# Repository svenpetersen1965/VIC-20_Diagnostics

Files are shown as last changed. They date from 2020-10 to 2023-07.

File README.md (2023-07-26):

# VIC-20_Diagnostics
This is a diagnostic  harness and the description of the diagnostic cartridge for the Commodore VIC-20, based on the original Commodore diagnostic harness and software.

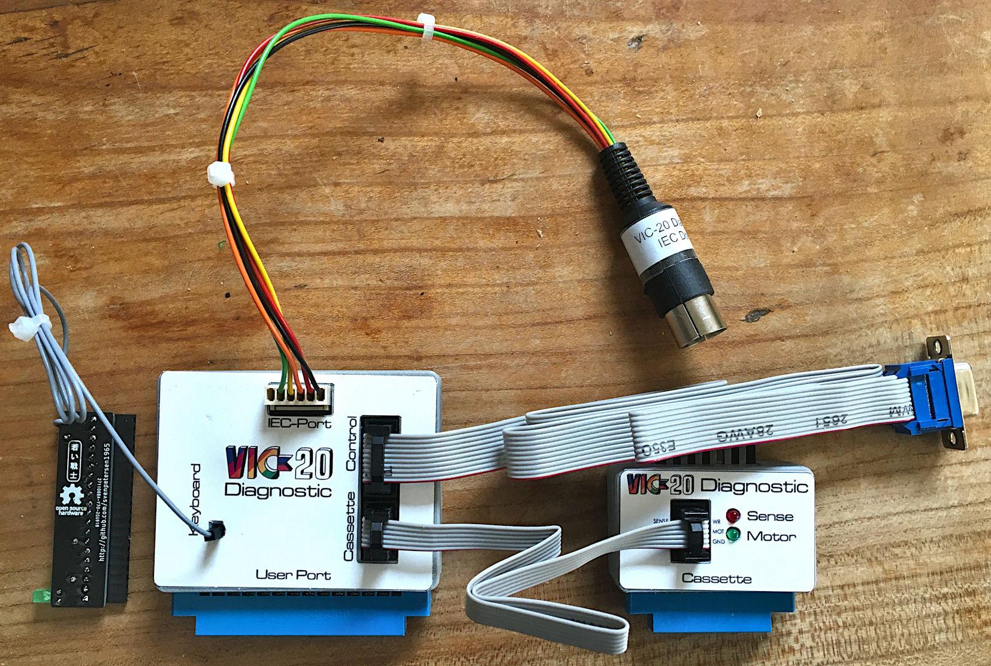
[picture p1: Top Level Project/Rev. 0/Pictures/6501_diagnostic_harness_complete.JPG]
Diagnostic Harness


The Diagnostic Cartridge is based on the design for the <a href="https://github.com/svenpetersen1965/Commodore-VIC-20-Super-Expander-II">VIC-20 Super Expander II</a> design.

Alternatively, the <a href="https://github.com/svenpetersen1965/VIC-20-Hyper-Expander">Hyper Expander</a> Cartridge can be used as a Diagnostic cartridge, too. All RAM (except the BLK5 8K block) can be installed for the Diagnostic.  

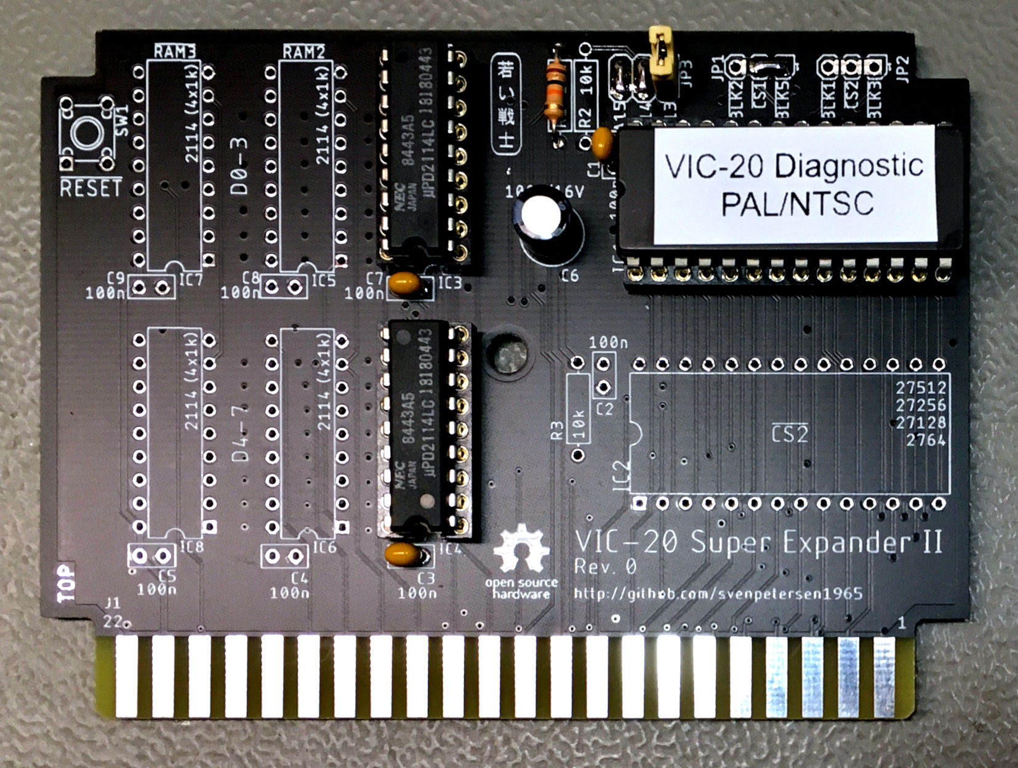
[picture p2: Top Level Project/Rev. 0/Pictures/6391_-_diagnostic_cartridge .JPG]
Diagnostic Cartridge


The general description of the VIC-20 Diagnostics can be found in the "Top-Level Project" folder.

The Rev. 1 of the User Port PCB just has a reduced part count.and a new logo.

Please find the (C64) cassette port adapter <a href="https://github.com/svenpetersen1965/C64-Diagnostic-Rev.-586220-Harness/tree/master/Diag586220_Harness/Diag586220_Cassette_Port">here</a>.

Please also refer to <a href="http://tech.guitarsite.de/vic-20_diagnostics.html">my website</a>

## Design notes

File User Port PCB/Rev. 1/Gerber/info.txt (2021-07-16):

      
       Board: VIC20_Diag_UP
       Rev.:  1
  
       Files:
       ======
  
       All Gerber files are generated in extended gerber format (RS274X)
       *.TOP        : Film top copper
       *.BOT        :  -"- bottom copper
       *.STC        :  -"- top soldermask 
       *.STS        :  -"- bottom soldermask
       *.PLC        :  -"- silk screen top
       *.DK         : Drills plated Through (Excellon)
       *.NDK        : Drills not plated Through (Excellon)
       *.OUT        : Board outline

       Board Size:
       ===========
       Length     :   55.0 mm
       Width      :   53.0 mm
       Thickness  :   1.6 mm
       Material   :   FR 4
       Copper     :   35 um
       Surface    :   HASL
       
       Remarks:
       ========
       Width >= 8mil
       Distance >= 6mil
       Drill >= 0.35mm

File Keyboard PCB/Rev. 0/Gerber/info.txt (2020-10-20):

      
       Board: VIC20_Diag_Keyboard
       Rev.:  0
  
       Files:
       ======
  
       All Gerber files are generated in extended gerber format (RS274X)
       *.TOP        : Film top copper
       *.BOT        :  -"- bottom copper
       *.STC        :  -"- top soldermask 
       *.STS        :  -"- bottom soldermask
       *.PLC        :  -"- silk screen top
       *.PLS        :  -"- silk screen bottom
       *.DK         : Drills plated Through (Excellon)
       *.NDK        : Drills not plated Through (Excellon)
       *.OUT        : Board outline

       Board Size:
       ===========
       Length     :   53.0 mm
       Width      :   14.0 mm
       Thickness  :   1.6 mm
       Material   :   FR 4
       Copper     :   35 um
       Surface    :   HASL
       
       Remarks:
       ========
       Width >= 8mil
       Distance >= 6mil
       Drill >= 0.35mm

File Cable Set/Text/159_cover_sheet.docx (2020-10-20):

Project Documentation

Commodore VIC-20: Diagnostic Cable Set

Project number: 159

Revision: 0

Date: 18.10.2020

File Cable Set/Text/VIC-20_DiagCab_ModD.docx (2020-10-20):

Commodore VIC-20: Diagnostics Cable Set – Rev. 0

Module Description

The Diagnostic cable set is one components of the VIC-20 Diagnostics Harness. It consists of four cables:

- The IEC Port Cable (Doc.-No. 159-3-01-**)
- The Control Port Cable (Doc.-No. 159-3-02-**)
- The Cassette Port Cable (Doc.-No. 159-3-03-**)
- The Keyboard RESTORE cable (Doc.-No. 159-3-04-**)

The Keyboard RESTORE cable is attached to the Keyboard PCB (Project-No. 156), a know serves as a strain relief.

The Control Port cable and the Cassette Port cable are both identical to the cables of the C64 diagnostic harness.

VIC-20_DiagCab_ModD.docx 18.10.2020 16:29 Drafted by Sven Petersen Page 2 of 2 Doc.-No.: 159-6-01-00

VIC-20_DiagCab_ModD.docx 18.10.2020 16:29 Drafted by Sven Petersen Page 1 of 1 Doc.-No.: 000-6-00-00

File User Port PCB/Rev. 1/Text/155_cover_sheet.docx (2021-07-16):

Project Documentation

Commodore VIC-20 Diagnostic User Port PCB

Project number: 155

Revision: 1

Date: 14.07.2021

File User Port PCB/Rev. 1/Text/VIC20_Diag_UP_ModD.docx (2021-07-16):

Commodore VIC-20 Diagnostic User Port PCB Rev. 1

Module Description

The VIC-20 Diagnostics User Port PCB provides most of the required feedbacks for the Commodore Diagnostic Software. Those are the feedbacks for the User Port, the IEC (serial) bus and the Cassette Port. Only the keyboard feedbacks are realized on the Diagnostic Keyboard PCB.

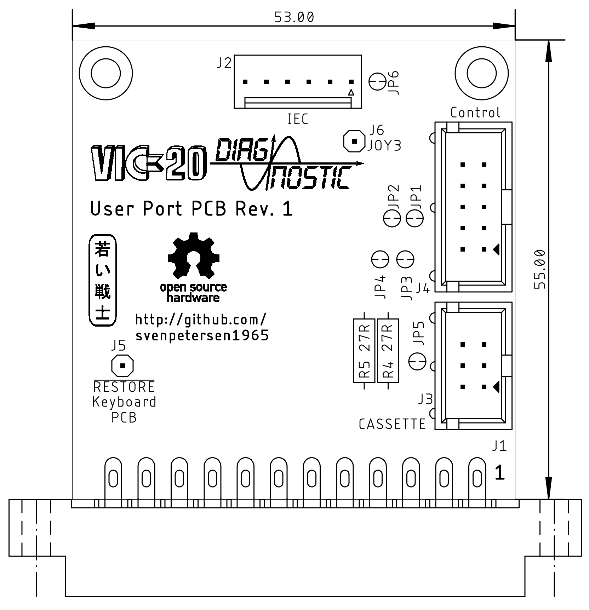
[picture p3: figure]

Figure 1: Dimensions of the User Port PCB

# Connectors

## User Port

J1- Edge Connector (2x12, 3.96mm pitch)

Pin | Signal | Pin | Signal
1 | GND | A | GND
2 | +5V | B | CB1
3 | /RESET | C | PB0
4 | JOY0 | D | PB1
5 | JOY1 | E | PB2
6 | JOY2 | F | PB3
7 | LIGHTPEN | H | PB4
8 | CASSSW | J | PB5
9 | ATN | K | PB6
10 | 9VAC(1) | L | PB7
11 | 9VAC(2) | M | CB2
12 | GND | N | GND

## IEC-Bus

J2 – KF2510, 6pin (compatible to Molex KK 254 series, 6p. - P/N 22272061)

Pin | Signal | DIN 6
1 | SQR IN | 1
2 | GND | 2
3 | ATN | 3
4 | CLK | 4
5 | DATA | 5
6 | n.c | -

## Cassette Port

J3 – 2x3 pin header for a ribbon cable connected to the cassette port PCB (project number 114, from the C64 Diagnostic Harness).

Pin | Signal | Pin | Signal
1 | GND | 2 | n.c.
3 | MOTOR | 4 | READ
5 | WRITE | 6 | SENSE

## Control Port

J4 – 2x5 pin header for a ribbon cable which connects via a D-SUB 9 (female) to the control port.

Pin | D-SUB | Signal | Pin | D-SUB | Signal
1 | 1 | JOY0 (up) | 2 | 6 | LIGHTPEN
3 | 2 | JOY1 (down) | 4 | 7 | +5VCTR1
5 | 3 | JOY2 (left) | 6 | 8 | n.c. (GND)
7 | 4 | JOY3 (right) | 8 | 9 | POTX
9 | 5 | POTY | 10 | - | n.c.

# Feedbacks

## User Port (J1)

Pin | Signal | | Signal | Pin
B | CB1 | « | IEC-Data | J2/Pin 5
C | PB0 | « | PB1 | D
E | PB2 | « | PB3 | F
H | PB4 | « | PB5 | J
K | PB6 | « | PB7 | L
M | CB2 | « | IEC-Clk | J2/Pin 4
9 | ATN | « | KB | See J5

## IEC-Bus (J2)

Pin | Signal | | Signal | Pin
1 | SQR_IN | « | ATN | 3
4 | IEC-Clk | « | CB2 (User Port) | J1/Pin M
5 | IEC-Data | « | CB1 (User Port) | J1/Pin B

## Cassette Port (J3)

Pin | Signal | | Signal | Pin
1 | GND | | n/c | 2
3 | MOTOR | Volt.div. | SENSE | 6
4 | READ | « | WRITE | 5

## Control Port (J4)

DSub | J4 Pin | Signal | | Signal | J4 Pin | DSub
1 | 1 | JOY0 | « | JOY1 | 3 | 2
6 | 2 | LIGHTPEN/FIRE | « | JOY2 | 5 | 3
9 | 8 | POTX | « | +5V (Control Port) | 4 | 7
5 | 9 | POTY | « | +5V (Control Port) | 4 | 7

The JOY3 signal is not tested by the original harness. It is connected to the solder pad J6 for experimental purposes.

## Note

The former 0Ω resistor have been replaced with closed (by default) solder bridges. This is to reduce the part count. They don’t serve any purpose, so leave them as is.

# 3D-printed Case

A 3D-printed case for the User Port PCB is available from this repository. The recommended screws are C2.9 x 9.5mm.

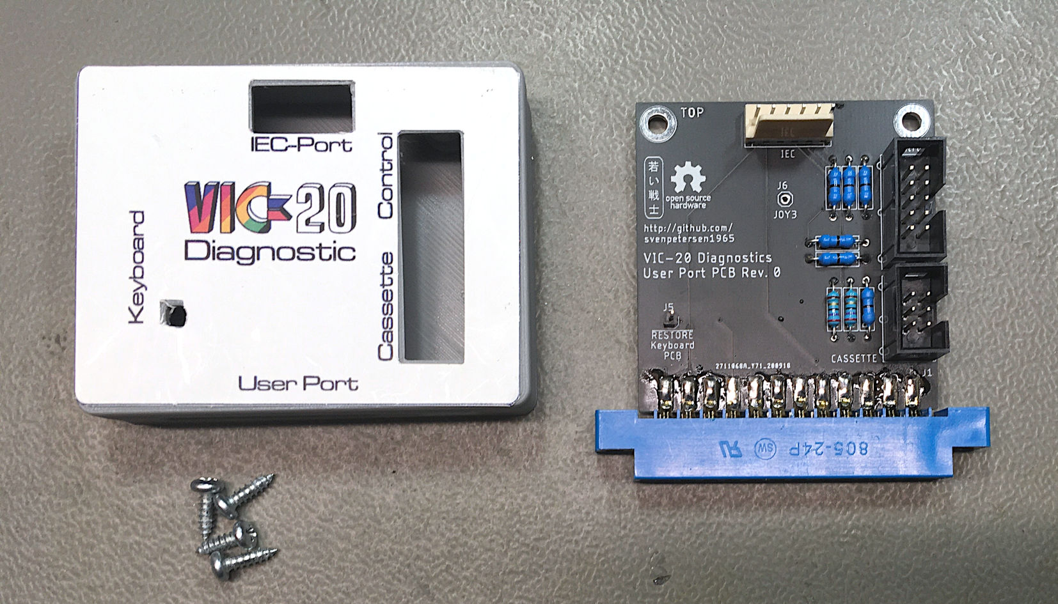
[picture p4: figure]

Figure 2: User Port PCB with 3D-printed case

# Revision History

## Rev. 0

- Fully working prototype

## Rev. 1

- 0Ω resistors replaced with closed solder bridges to reduce part count
- Cool new logo
- Not yet tested, but low risk modification. Ready for production.

VIC20_Diag_UP_ModD.docx 16.07.2021 13:00 Drafted by Sven Petersen Page 2 of 2 Doc.-No.: 155-6-01-01

VIC20_Diag_UP_ModD.docx 16.07.2021 13:00 Drafted by Sven Petersen Page 1 of 1 Doc.-No.: 000-6-00-00

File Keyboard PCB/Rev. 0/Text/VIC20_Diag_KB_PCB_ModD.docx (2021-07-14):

Commodore VIC-20 Diagnostic Keyboard PCB Rev. 0

Module Description

The Keyboard PBC provides the feedbacks for the keyboard connector, which are required for the Commodore VIC-20 Diagnostic software. The LED works as an alternative Power LED.

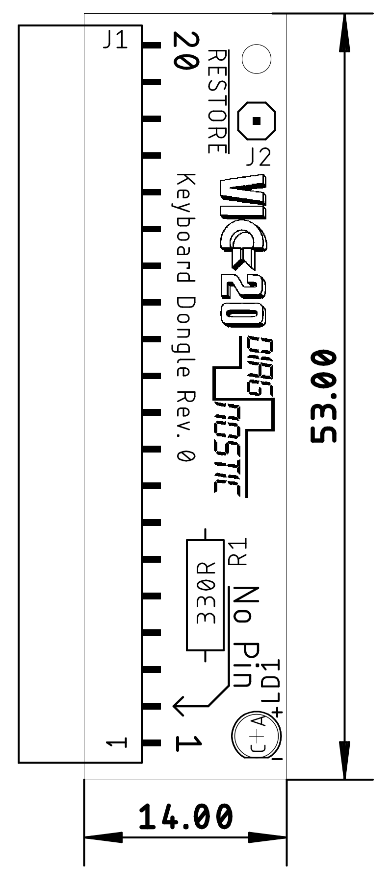
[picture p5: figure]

Figure 1: Dimensions of the Keyboard PCB

# Connectors

## Keyboard Connector (J1)

Pin | Signal
1 | GND
2 | No Pin
3
4 | +5V
5 | COL7
6 | COL6
7 | COL5
8 | COL4
9 | COL3
10 | COL2
11 | COL1
12 | COL0
13 | ROW7
14 | ROW6
15 | ROW5
16 | ROW4
17 | ROW3
18 | ROW2
19 | ROW1
20 | ROW0

## Cable (J2)

This is a solder pad for the RESTORE Cable (Doc.-No. 159-3-04-**) from the cable set. The cable is soldered to the pad and a knot serves as a strain relief.

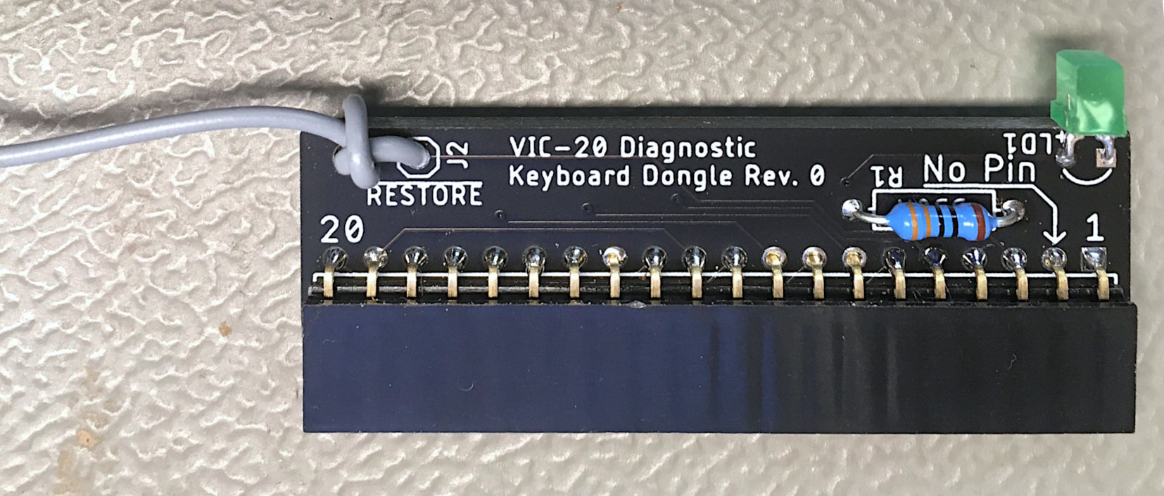
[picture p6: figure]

Figure 2: Keyboard PCB with the RESTORE cable soldered to J2 and tied to the PCB

This cable is connected to a single pin of the User Port PCB.

# Interconnects

Signal | | Signal
| → | User Port Pin 9 (ATN)
COL7 | « | ROW7
COL6 | « | ROW6
COL5 | « | ROW5
COL4 | « | ROW4
COL3 | « | ROW3
COL2 | « | ROW2
COL1 | « | ROW1
COL0 | « | ROW0

VIC20_Diag_KB_PCB_ModD.docx 14.07.2021 17:06 Drafted by Sven Petersen Page 2 of 2 Doc.-No.: 156-6-01-00

VIC20_Diag_KB_PCB_ModD.docx 14.07.2021 17:06 Drafted by Sven Petersen Page 1 of 1 Doc.-No.: 000-6-00-00

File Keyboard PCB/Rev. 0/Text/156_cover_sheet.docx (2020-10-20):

Project Documentation

Commodore VIC-20 Diagnostic Keyboard PCB

Project number: 156

Revision: 0

Date: 15.09.2020

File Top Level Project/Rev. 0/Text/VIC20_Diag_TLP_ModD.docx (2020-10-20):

Commodore VIC-20 Diagnostics (Top-Level Project) Rev. 0

Module Description

# Abstract

This is the top-level project of the VIC-20 diagnostic harness and cartridge. The whole diagnostics set consists of:

- A Diagnostic Cartridge
- A User Port PCB
- A Keyboard PCB
- A Cassette Port PCB
- A Cable Set


Figure 1: The complete Diagnostic Harness

# Diagnostics Cartridge

The diagnostic cartridge is based on the Super Expander II. It contains the diagnostic software in an EPROM and 1kByte of RAM.


Figure 2: Diagnostics Cartridge

There are two versions of the (original Commodore) test software, which were downloaded from www.zimmers.net (http://www.zimmers.net/anonftp/pub/cbm/firmware/misc/vc-20diag/index.html). One version is for the PAL VIC-20. It displays “VC-20” (like the name of the computer in Germany). The other version is for NTSC VIC-20 (it displays “VIC-20”).

Both software versions work in the IC1 socket, the chip select hardwired to (the base address is $A000). Thus, the solder bridge at JP1 as seen in Figure 2.

Since there are only two versions of the diagnostic software, two jumpers (A15 and A14) on JP3 can be hardwired (which is valid for a 27C512 EPROM). A 10k for R1 and a single jumper is required to select one of the two software versions.

EPROM | Solder bridges closed | Resistors placed
27C512 | A14, A15 | R1
27C256 | A15 | R1, R2
27C128 | - | R1, R2, R3

The EPROM IC1requires a 100n capacitor in position C1.

The RAM is only 1kByte. That are two 2114 (1kx4) SRAM at position IC3 and IC4 (with 100n at C7 and C3).

The Super Expander II cartridge can be found at github: https://github.com/svenpetersen1965/Commodore-VIC-20-Super-Expander-II

# The User Port PCB

The User Port PCB is especially developed for this project. The complete documentation, Gerber data and design files are available on github:

https://github.com/svenpetersen1965/VIC-20_Diagnostics

A 3D printable case is provided in the same repository.

# The Keyboard PCB

The Keyboard PCB is especially developed for this project. The complete documentation, Gerber data and design files are available on github:

https://github.com/svenpetersen1965/VIC-20_Diagnostics

# The Cassette Port PCB

The Cassette Port PCB is identical to the Cassette Port PCB of the C64 Diagnostic harness. It is available from github:

https://github.com/svenpetersen1965/C64-Diagnostic-Rev.-586220-Harness

A 3D printable case can be found in the same repository.

All required feedbacks are realized on the User Port PCB, which connects to the Cassette Port PCB via a ribbon cable. The cassette port PCB is free of any typical feedbacks. Two signals are indicated with LEDs.

# The Cable Set

The cable set consists of four cables:

- The IEC Port Cable
- The Control Port Cable
- The Cassette Port Cable
- The Keyboard RESTORE cable

The Control Port cable and the Cassette Port cable are identical to the C64 Diagnostic Harness cables.

The IEC-Port cable connects the IEC port to the User Port PCB, which provides the required feed backs.

The RESTORE cable connects the Keyboard PCB to the User Port PCB. This is a simple DuPont wire, which is soldered to the Keyboard PCB on one side.

The documentation for the Cable Set can be found on github:

https://github.com/svenpetersen1965/VIC-20_Diagnostics

VIC20_Diag_TLP_ModD.docx 20.10.2020 14:21 Drafted by Sven Petersen Page 2 of 2 Doc.-No.: 161-6-01-00

VIC20_Diag_TLP_ModD.docx 20.10.2020 14:21 Drafted by Sven Petersen Page 1 of 1 Doc.-No.: 000-6-00-00

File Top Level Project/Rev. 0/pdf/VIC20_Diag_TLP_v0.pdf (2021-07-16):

# Project Documentation

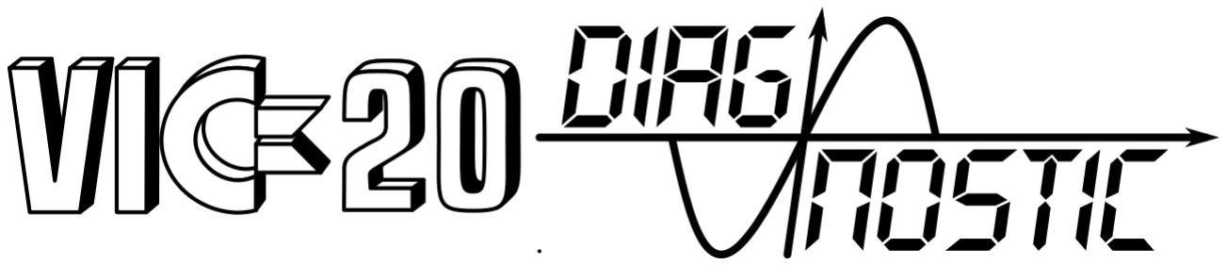
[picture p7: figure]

## Commodore VIC-20 Diagnostics (Top-Level Project)

## Project number: 161

## Revision: 0

## Date: 20.10.2020

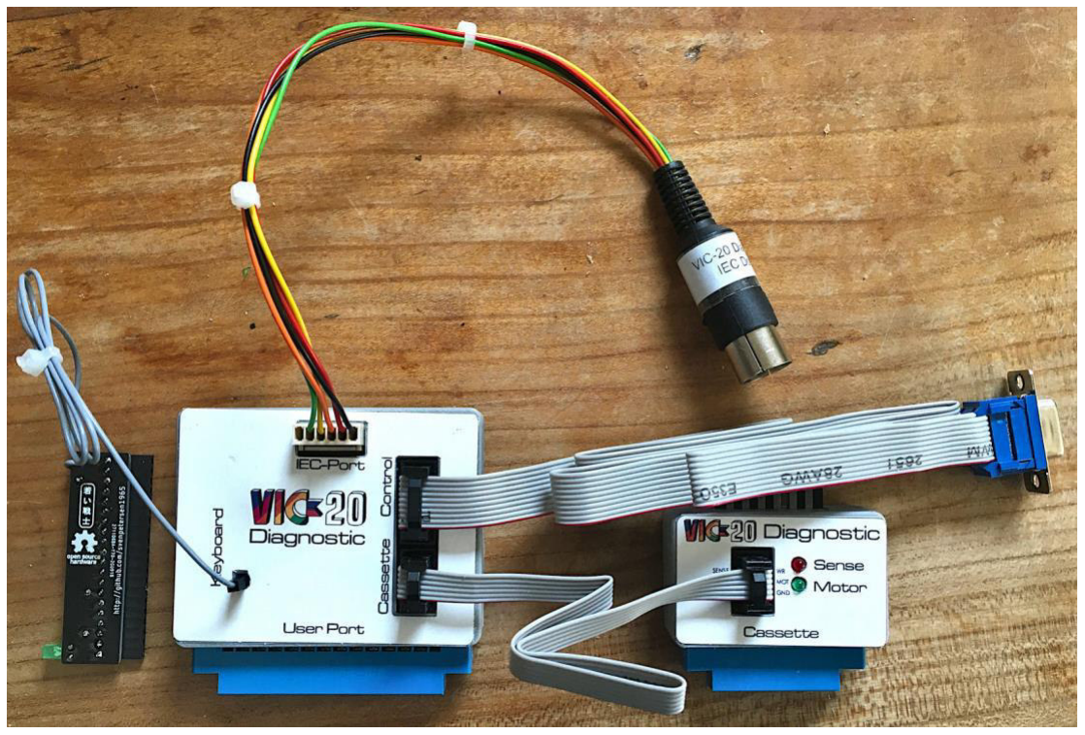
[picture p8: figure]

VIC20_Diag_TLP_ModD.docx | | 20.10.2020 14:21
Drafted by Sven Petersen | Page 1 of 3 | Doc.-No.: 161-6-01-00

### Commodore VIC-20 Diagnostics (Top-Level Project) Rev. 0

### Module Description

## Abstract

This is the top-level project of the VIC-20 diagnostic harness and cartridge. The whole diagnostics set consists of:

- A Diagnostic Cartridge
- A User Port PCB
- A Keyboard PCB
- A Cassette Port PCB
- A Cable Set

Figure 1: The complete Diagnostic Harness

## Diagnostics Cartridge

The diagnostic cartridge is based on the Super Expander II. It contains the diagnostic software in an EPROM and 1kByte of RAM.

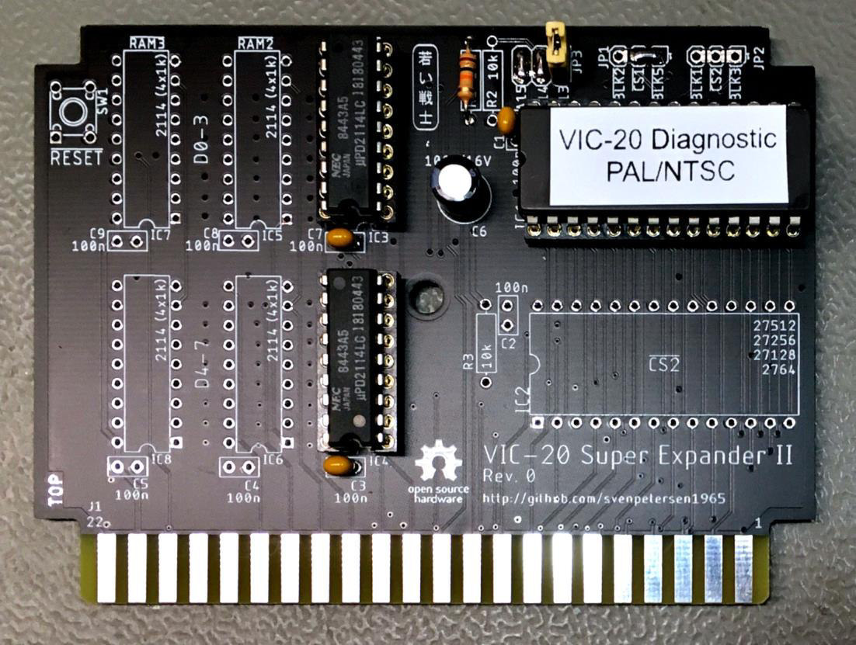
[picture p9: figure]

Drafted by Sven Petersen | Page 2 of 3 | Doc.-No.: 161-6-01-00

Figure 2: Diagnostics Cartridge

There are two versions of the (original Commodore) test software, which were downloaded from www.zimmers.net. (http://www.zimmers.net/anonftp/pub/cbm/firmware/misc/vc-20diag/index.html) One version is for the PAL VIC-20. It displays “VC-20” (like the name of the computer in Germany). The other version is for NTSC VIC-20 (it displays “VIC-20”).

Both software versions work in the IC1 socket, the chip select CS1 hardwired to BLK5 (the base address is $A000). Thus, the solder bridge at JP1 as seen in Figure 2.

Since there are only two versions of the diagnostic software, two jumpers (A15 and A14) on JP3 can be hardwired (which is valid for a 27C512 EPROM). A 10k for R1 and a single jumper is required to select one of the two software versions.

EPROM | Solder bridges closed | Resistors placed
27C512 | A14, A15 | R1
27C256 | A15 | R1, R2
27C128 | - | R1, R2, R3

The EPROM IC1requires a 100n capacitor in position C1.

The RAM is only 1kByte. That are two 2114 (1kx4) SRAM at position IC3 and IC4 (with 100n at C7 and C3).

The Super Expander II cartridge can be found at github: https://github.com/svenpetersen1965/Commodore-VIC-20-Super-Expander-II

## The User Port PCB

The User Port PCB is especially developed for this project. The complete documentation, Gerber data and design files are available on github:

Drafted by Sven Petersen | Page 3 of 3 | Doc.-No.: 161-6-01-00

https://github.com/svenpetersen1965/VIC-20_Diagnostics

A 3D printable case is provided in the same repository.

## The Keyboard PCB

The Keyboard PCB is especially developed for this project. The complete documentation, Gerber data and design files are available on github:

https://github.com/svenpetersen1965/VIC-20_Diagnostics

## The Cassette Port PCB

The Cassette Port PCB is identical to the Cassette Port PCB of the C64 Diagnostic harness. It is available from github:

https://github.com/svenpetersen1965/C64-Diagnostic-Rev.-586220-Harness

A 3D printable case can be found in the same repository.

All required feedbacks are realized on the User Port PCB, which connects to the Cassette Port PCB via a ribbon cable. The cassette port PCB is free of any typical feedbacks. Two signals are indicated with LEDs.

## The Cable Set

The cable set consists of four cables:

- The IEC Port Cable
- The Control Port Cable
- The Cassette Port Cable
- The Keyboard RESTORE cable

The Control Port cable and the Cassette Port cable are identical to the C64 Diagnostic Harness cables.

The IEC-Port cable connects the IEC port to the User Port PCB, which provides the required feed backs.

The RESTORE cable connects the Keyboard PCB to the User Port PCB. This is a simple DuPont wire, which is soldered to the Keyboard PCB on one side.

The documentation for the Cable Set can be found on github:

https://github.com/svenpetersen1965/VIC-20_Diagnostics

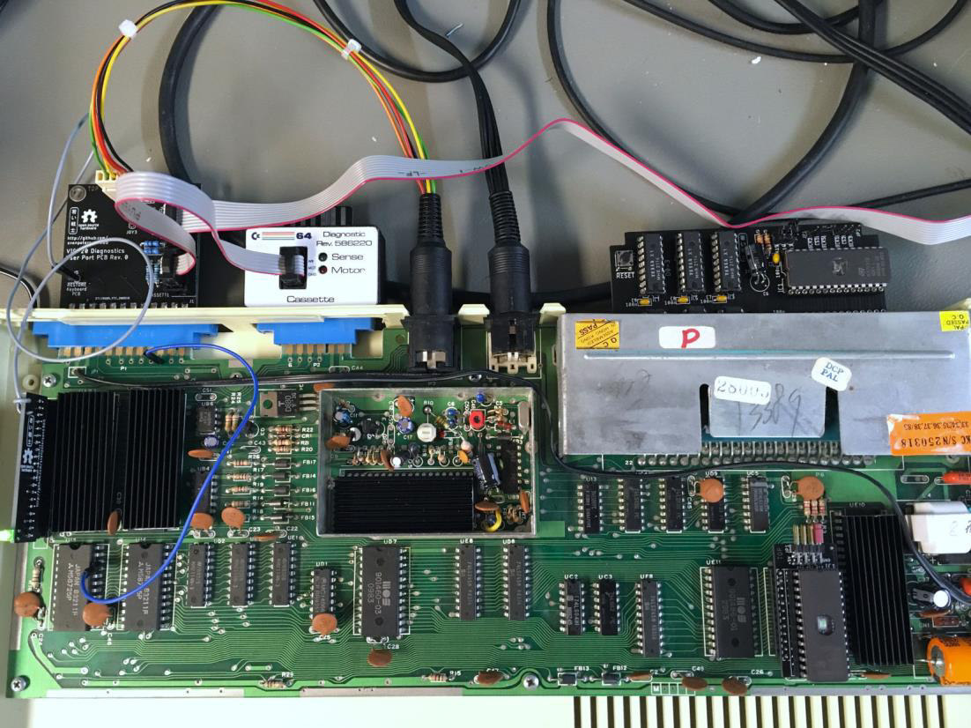
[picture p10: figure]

VIC20_Diag_TLP_Testing.docx | | 20.10.2020 16:35
Drafted by Sven Petersen | Page 1 of 3 | Doc.-No.: 161-6-02-00

### Commodore VIC-20 Diagnostics Rev. 0

### Testing

## Test Setup

The complete Diagnostics Harness (Rev. 0) and Diagnostics Cartridge (Super Expander II Rev. 0 with the Commodore Diagnostic Firmware) was tested on a VIC-20 ASSY 250403 Rev. D.

Figure 1: Test Setup

## Test Execution

The test was first carried out with a Super Expander II with 3kByte of RAM. The Test was running without any problems. Later, the not required upper 2k of RAM were removed from the board, the execution was without any problem, either.

The (Commodore) Test software stops at the first problem and the screen starts flashing. In case no problem is diagnosed, the software is looping infinitely.

There are two versions of the test software. One is for the NTSC VIC-20, the other for the PAL VIC-20. Both were working without problems on a PAL VIC-20. The position of the active was different, though.

The Feedbacks were tested by removing the feedback cables, one by one. The missing feedbacks were detected for the IEC-Bus, the Cassette Port and the Control Port. Removing the Keyboard PCB does not report and “open” like in the C64 Diagnostics Rev. 586220. It did not look like the feedbacks were diagnosed, so, one feedback (not all) was opened. The problem was properly detected.

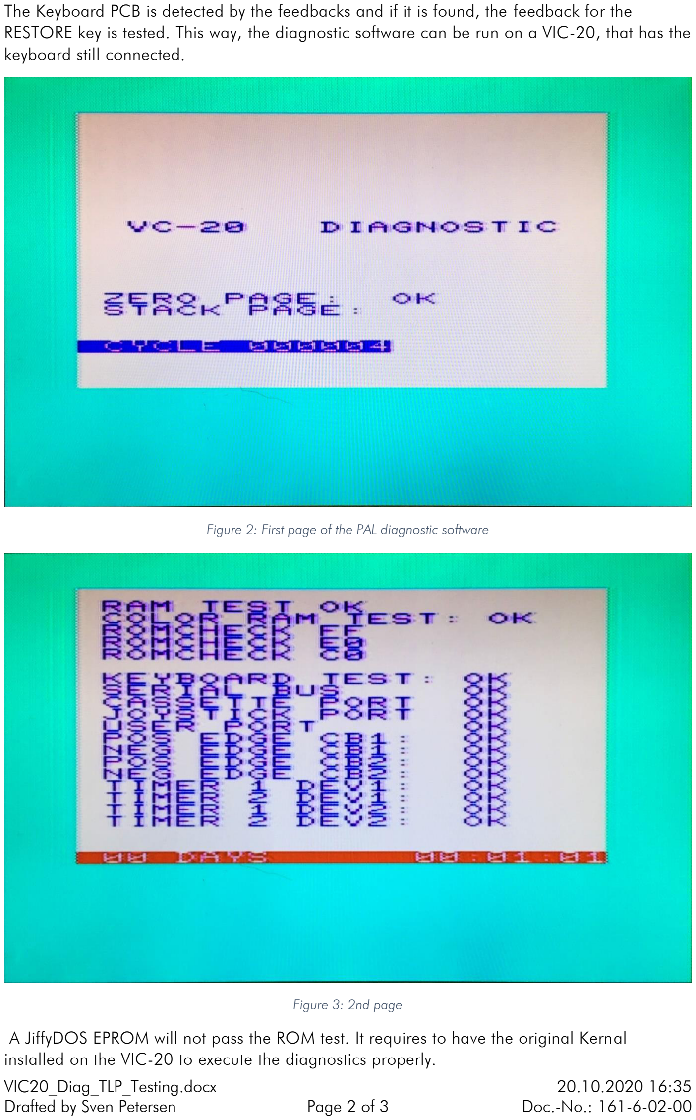
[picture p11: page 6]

Drafted by Sven Petersen | Page 2 of 3 | Doc.-No.: 161-6-02-00

The Keyboard PCB is detected by the feedbacks and if it is found, the feedback for the RESTORE key is tested. This way, the diagnostic software can be run on a VIC-20, that has the keyboard still connected.

Figure 2: First page of the PAL diagnostic software

Figure 3: 2nd page

A JiffyDOS EPROM will not pass the ROM test. It requires to have the original Kernal installed on the VIC-20 to execute the diagnostics properly.

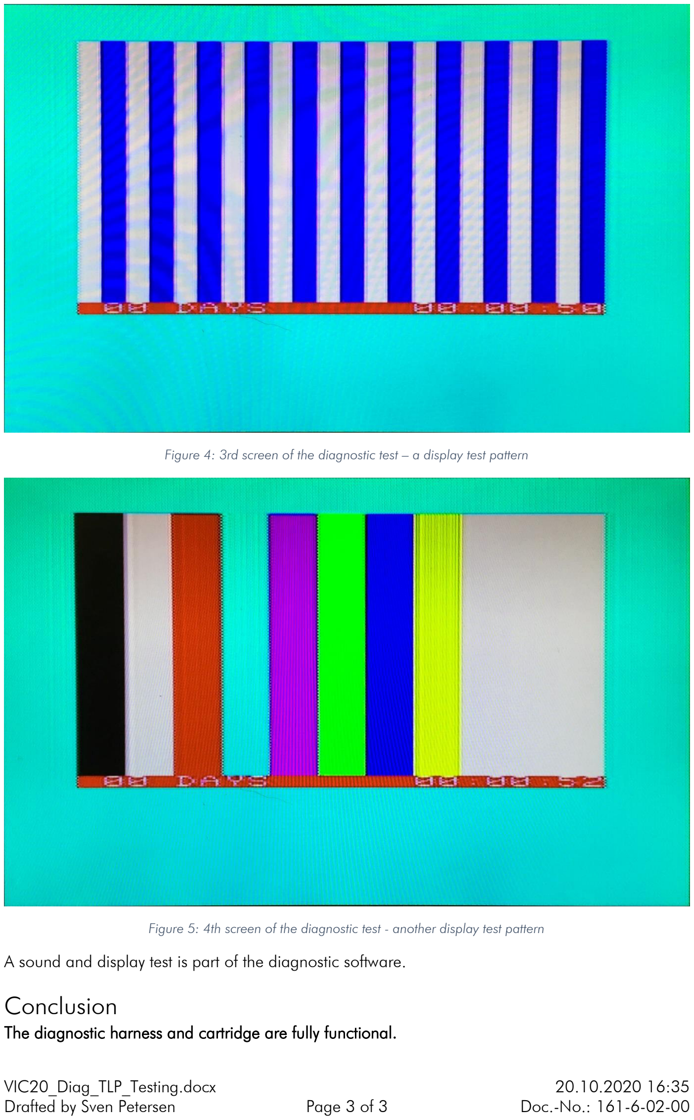
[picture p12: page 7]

Drafted by Sven Petersen | Page 3 of 3 | Doc.-No.: 161-6-02-00

Figure 4: 3rd screen of the diagnostic test – a display test pattern

Figure 5: 4th screen of the diagnostic test - another display test pattern

A sound and display test is part of the diagnostic software.

## Conclusion

The diagnostic harness and cartridge are fully functional.

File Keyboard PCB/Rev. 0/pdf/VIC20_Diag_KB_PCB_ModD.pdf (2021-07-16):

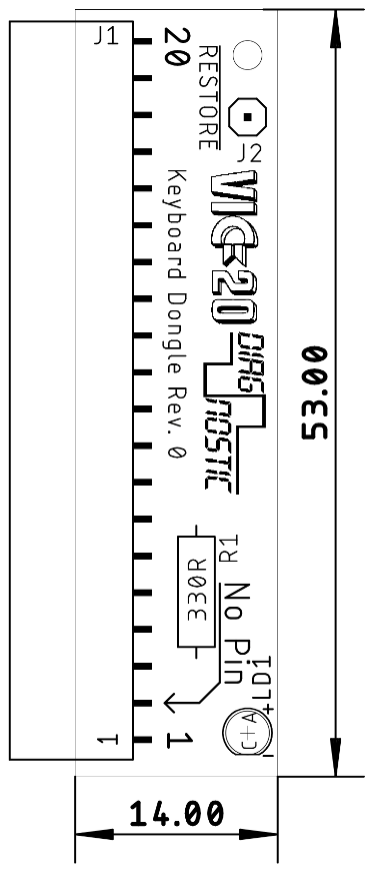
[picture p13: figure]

VIC20_Diag_KB_PCB_ModD.docx | | 14.07.2021 17:06
Drafted by Sven Petersen | Page 1 of 2 | Doc.-No.: 156-6-01-00

### Commodore VIC-20 Diagnostic Keyboard PCB Rev. 0

### Module Description

The Keyboard PBC provides the feedbacks for the keyboard connector, which are required for the Commodore VIC-20 Diagnostic software. The LED works as an alternative Power LED.

Figure 1: Dimensions of the Keyboard PCB

## Connectors

### Keyboard Connector (J1)

Pin | Signal
1 | GND
2 | No Pin
3 | RESTORE
4 | +5V
5 | COL7
6 | COL6
7 | COL5
8 | COL4
9 | COL3
10 | COL2
11 | COL1
12 | COL0
13 | ROW7
14 | ROW6
15 | ROW5
16 | ROW4

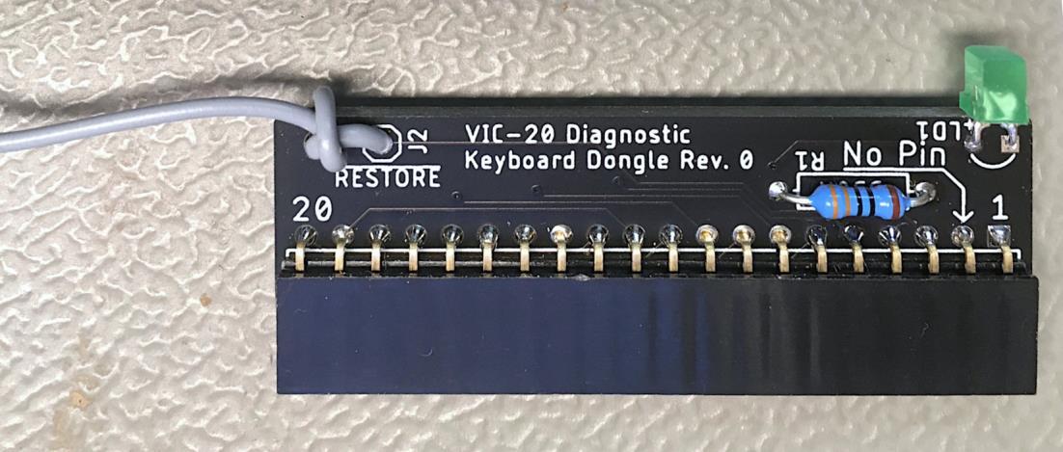
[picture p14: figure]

VIC20_Diag_KB_PCB_ModD.docx | | 14.07.2021 17:06
Drafted by Sven Petersen | Page 2 of 2 | Doc.-No.: 156-6-01-00
Pin | Signal
17 | ROW3
18 | ROW2
19 | ROW1
20 | ROW0

### RESTORE Cable (J2)

This is a solder pad for the RESTORE Cable (Doc.-No. 159-3-04-**) from the cable set. The cable is soldered to the pad and a knot serves as a strain relief.

Figure 2: Keyboard PCB with the RESTORE cable soldered to J2 and tied to the PCB

This cable is connected to a single pin of the User Port PCB.

## Interconnects

Signal | Signal
RESTORE | → | User Port Pin 9 (ATN)
COL7 | « | ROW7
COL6 | « | ROW6
COL5 | « | ROW5
COL4 | « | ROW4
COL3 | « | ROW3
COL2 | « | ROW2
COL1 | « | ROW1
COL0 | « | ROW0

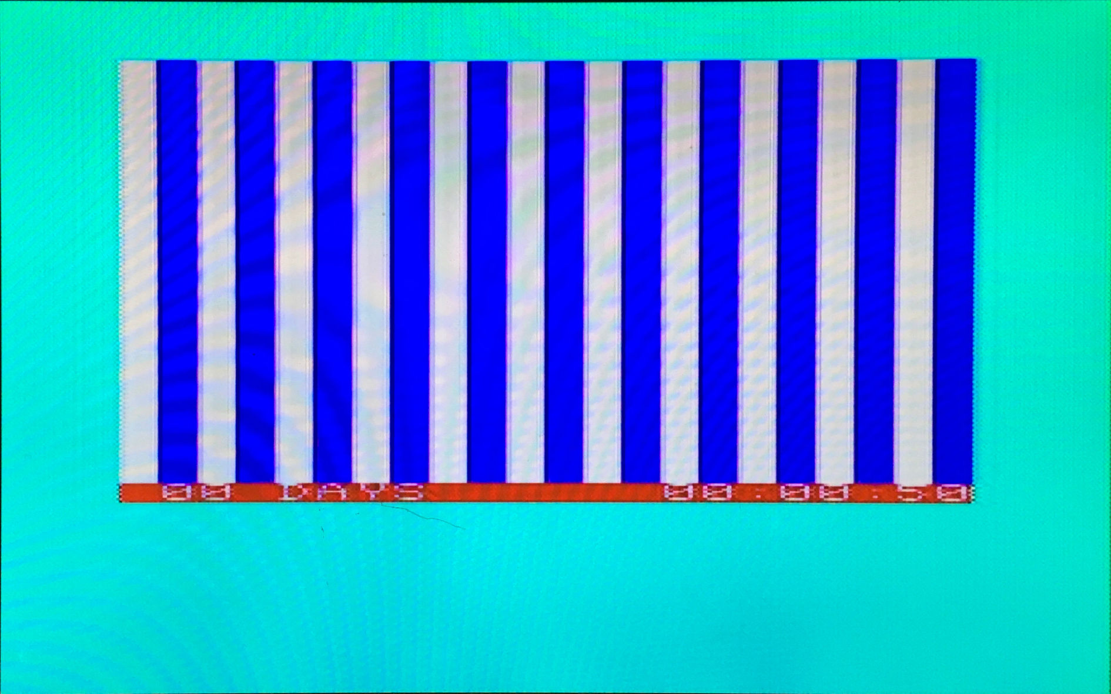
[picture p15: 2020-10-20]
Top Level Project/Rev. 0/Pictures/6357_-_victest_page3.JPG

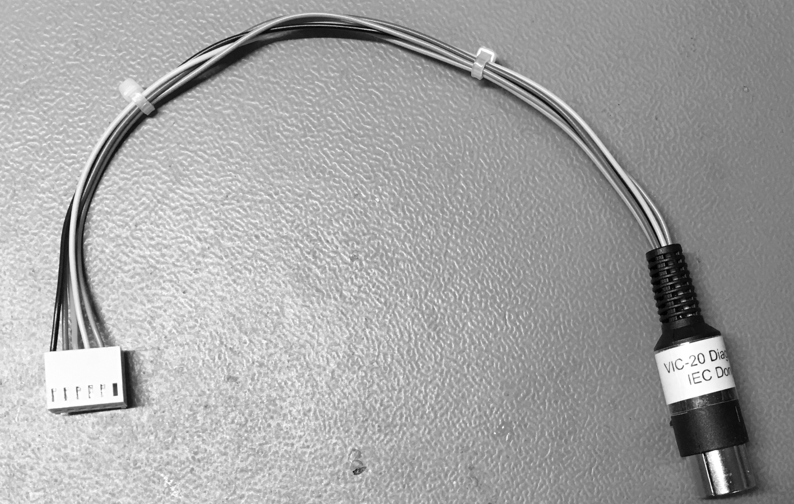
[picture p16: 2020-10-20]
Cable Set/Pictures/6409_IEC.PNG

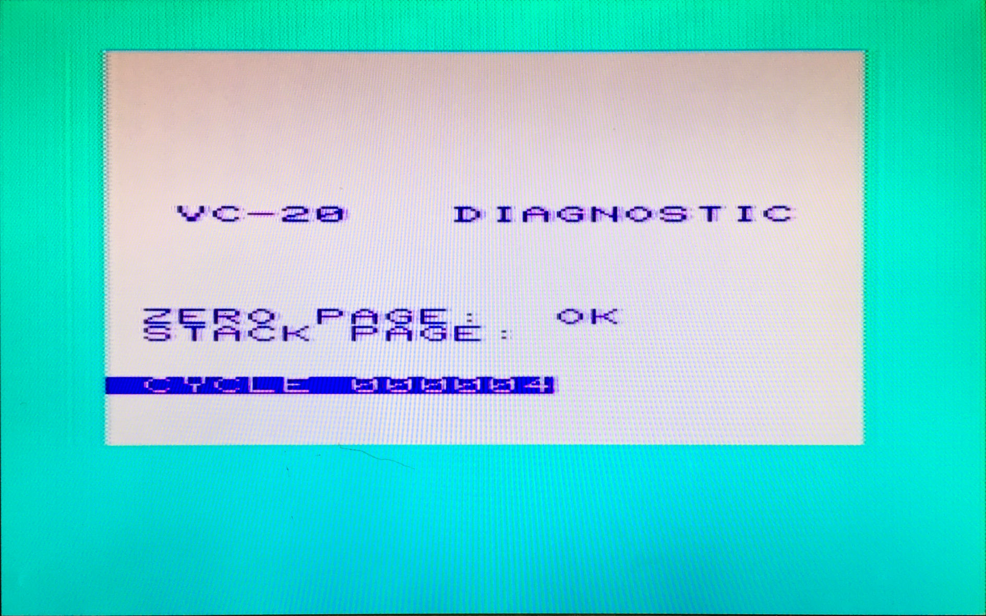
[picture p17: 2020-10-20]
Top Level Project/Rev. 0/Pictures/6360_-_victest_page1.JPG

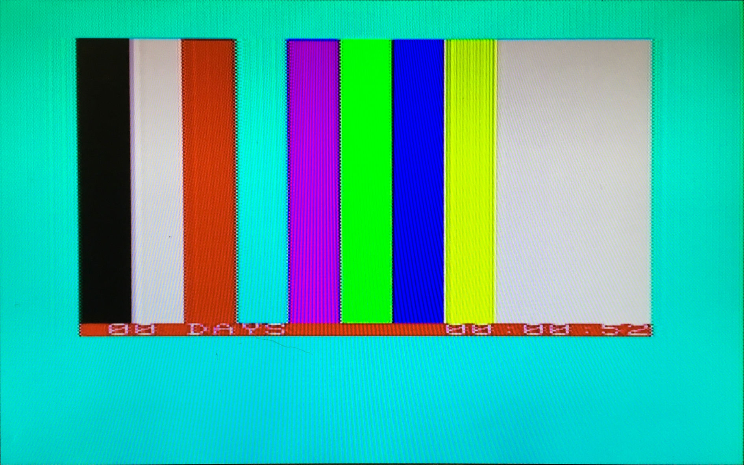
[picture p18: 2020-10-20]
Top Level Project/Rev. 0/Pictures/6358_-_victest_page4.JPG

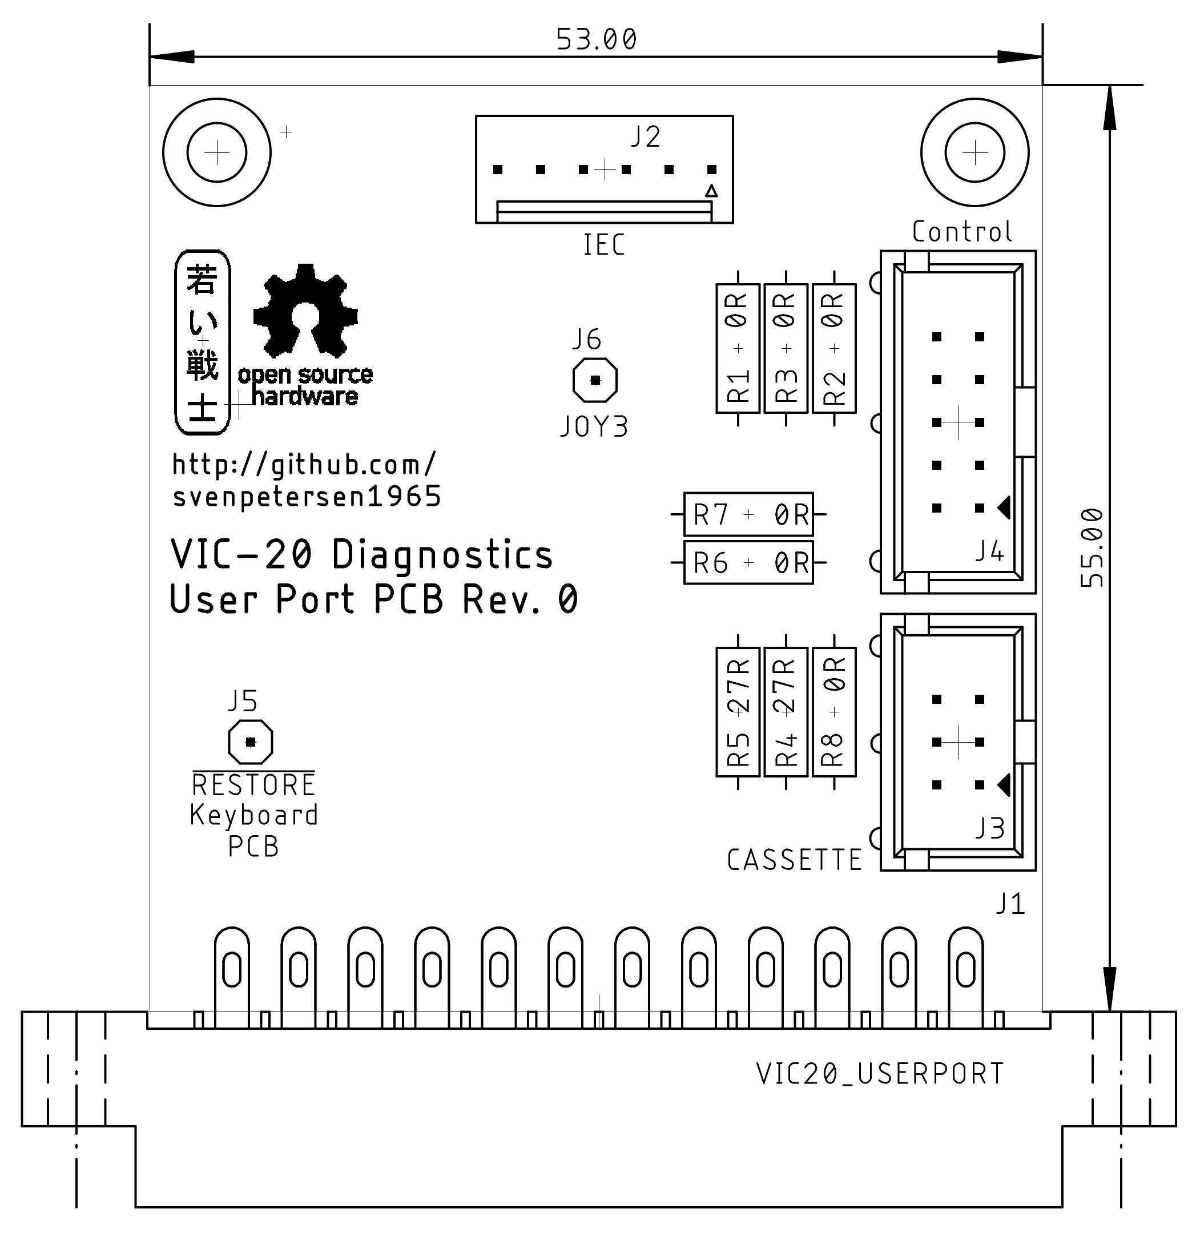
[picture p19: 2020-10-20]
User Port PCB/Rev. 0/pictures/Diag_UP_dimensions.png

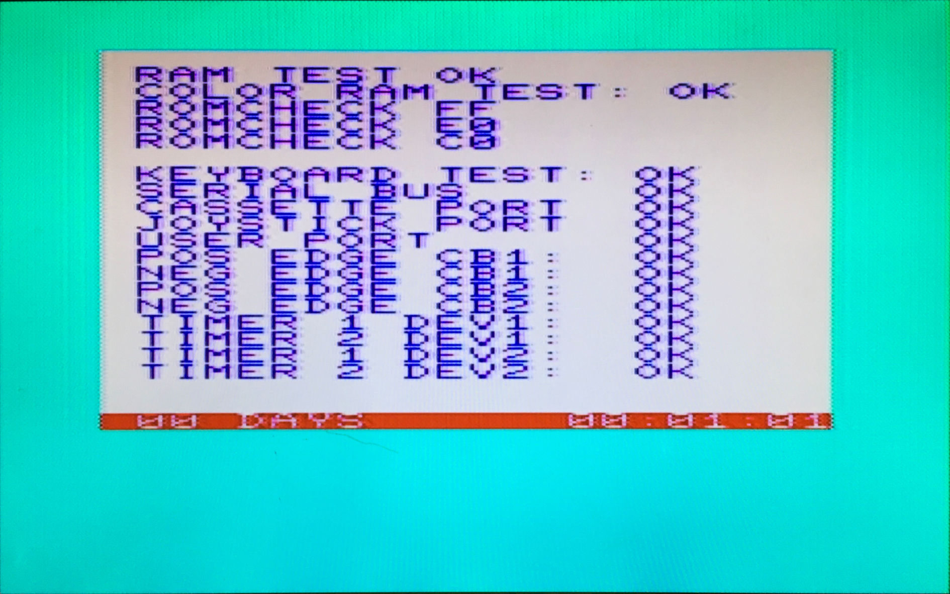
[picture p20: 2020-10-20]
Top Level Project/Rev. 0/Pictures/6361_-_victest_page2.JPG

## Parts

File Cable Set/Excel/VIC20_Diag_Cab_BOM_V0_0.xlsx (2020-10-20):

VIC-20 Diagnostic Cable Set Rev. 0
Bill of Material Rev. 0.0
Pos. | Qty | Value | Comment
1 | 1 | KF2510/6 way | Crimp housing KF2510 (6 way) (Reichelt RND 205-00666) or AliExpress or Molex 22-01-3067 (Reichelt MOLEX 22013067)
2 | 5 | KF2510 Terminals | Crimp Terminals for KF2510 (Reichelt RND 205-00696) or AliExpress or Molex 0850-0032 (Reichelt MOLEX 8500032). Attention: KF2510 crimp terminals do not mic with Molex housings and vice versa.
3 | 5 | 25cm Wire AWG24 | or 5 way ribbon cable AWG28. Different colors are recommeded
4 | 2 | cable ties | small cable ties
5 | 1 | DIN Plug 6 way | e.g. Hirschmann MAS60 (Reichelt MAS 60)
6 | 1 | IDC ribbon cable socket 10 way | e.g. Reichelt IDC Ribbon Cable Socket 10P
7 | 1 | 64cm ribbon cable | 10w, AWG28, 1.27mm pitch (standard)
8 | 1 | Dsub 9, for ribbon cable | e.g. Reichelt D-SUB BU 09FB
9 | 2 | IDC ribbon cable socket 6 way | e.g. Reichelt RND 205-00680
10 | 1 | 11cm ribbon cable | 6w, AWG28, 1.27mm pitch (standard) (or 25cm for combining with C128 diagnostics)
11 | 1 | 18cm Wire AWG24
12 | 1 | DuPont crimp terminal | (DuPont aka MiniPV). Ebay, AliExpress, other online stores
13 | 1 | DuPont housing 1 way | (DuPont aka MiniPV). Ebay, AliExpress, other online stores

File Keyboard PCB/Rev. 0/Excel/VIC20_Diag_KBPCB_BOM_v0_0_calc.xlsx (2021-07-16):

VIC-20 Diagnostic Keyboard PCB Rev. 0
Bill of Material Rev. 0.0
Pos. | Qty | Value | €/ea | € | Comment
1 | 1 | 156-2-01-00 | 1.00 € | 1.00 € | 2 layer, Cu 35µ, HASL, 53.0mm x 14.0mm, 1.6mm FR4
2 | 1 | 3mm/green | 0.20 € | 0.20 € | LED
3 | 1 | Restore cable | 0.20 € | 0.20 € | Cable (Doc.-No. 159-3-04-**) from cable set soldered to J2, see module description
4 | 1 | 330R | 0.80 € | 0.80 € | 1/4 Watt, 5%
5 | 1 | BL1-85AXX-20U | 0.45 € | 0.45 € | 20 socket connector, 90°, 2.54mm pitch. E.g. MPE Garry, Reichelt BL 1x20W8 2,54
 |  | Total |  | 2.65 €

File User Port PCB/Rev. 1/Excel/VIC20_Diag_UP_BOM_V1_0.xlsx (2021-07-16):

VIC-20 Diagnostic User Port PCB Rev. 1
Bill of Material Rev. 1.0
Pos. | Qty | Value | Footprint | Ref.-No. | Comment
1 | 1 | 155-2-01-01 | 2 Layer | PCB Rev. 1 | 2 layer, Cu 35µ, HASL, 55.0mm x 53.0mm, 1.6mm FR4
2 | 1 | 2x3 box connector | 2X03WV | J3 | e.g. Reichelt WSL 6G
3 | 1 | 2x5 box connector | 2X05WV | J4 | e.g. Reichelt WSL 10G
4 | 1 | KF2510-6P | 6410-6P | J2 | Reichelt (RND 205-00675), AliExpress or Molex 6410/22-27-2061 (Reichelt MOLEX 22272061)
5 | 1 | Pin header, 1 pin | 1X01 | J5 | Pin Header, e.g. Reichelt RND 205-00622
6 | 0 | do not place | 1X01 | J6 | do not place
7 | 2 | 27R | R-10 | R4, R5 | Metal film resistor, 1/2 W, 5% or better
8 | 1 | 2x12, 3.96mm pitch | USERPORT | J1 | edge connector, VIC-20 user port

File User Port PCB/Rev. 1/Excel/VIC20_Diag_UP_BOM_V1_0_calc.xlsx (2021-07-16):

VIC-20 Diagnostic User Port PCB/Calculation Rev. 1
Bill of Material Rev. 1.0
Pos. | Qty | Value | €/ea | € | Comment
1 | 1 | 155-2-01-01 | 1.00 € | 1.00 € | 2 layer, Cu 35µ, HASL, 55.0mm x 53.0mm, 1.6mm FR4
2 | 1 | 2x3 box connector | 0.19 € | 0.19 € | e.g. Reichelt WSL 6G
3 | 1 | 2x5 box connector | 0.10 € | 0.10 € | e.g. Reichelt WSL 10G
4 | 1 | KF2510-6P | 0.20 € | 0.20 € | Reichelt (RND 205-00675), AliExpress or Molex 6410/22-27-2061 (Reichelt MOLEX 22272061)
5 | 1 | Pin header, 1 pin | 0.03 € | 0.03 € | Pin Header, e.g. Reichelt RND 205-00622
6 | 0 | do not place | 0.00 € | 0.00 € | do not place
7 | 2 | 27R | 0.08 € | 0.16 € | Metal film resistor, 1/2 W, 5% or better
8 | 1 | 2x12, 3.96mm pitch | 3.00 € | 3.00 € | edge connector, VIC-20 user port
 |  | Total |  | 4.68 €

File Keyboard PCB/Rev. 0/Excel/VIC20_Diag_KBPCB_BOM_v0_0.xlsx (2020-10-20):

VIC-20 Diagnostic Keyboard PCB Rev. 0
Bill of Material Rev. 0.0
Pos. | Qty | Value | Footprint | Ref.-No. | Comment
1 | 1 | 156-2-01-00 | 2 Layer | PCB Rev. 0 | 2 layer, Cu 35µ, HASL, 53.0mm x 14.0mm, 1.6mm FR4
2 | 1 | 3mm/green | 3MM | LD1 | LED
3 | 1 | Restore cable | 1X01 | J2 | Cable (Doc.-No. 159-3-04-**) from cable set soldered to J2, see module description
4 | 1 | 330R | R-10 | R1 | 1/4 Watt, 5%
5 | 1 | BL1-85AXX-20U | BL1-85AXX-20U | J1 | 20 socket connector, 90°, 2.54mm pitch. E.g. MPE Garry, Reichelt BL 1x20W8 2,54

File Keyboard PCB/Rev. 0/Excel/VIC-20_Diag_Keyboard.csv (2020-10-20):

Qty | Value | Package | Parts | Description
1 |  | 3MM | LD1
1 |  | 1X01 | J2
1 | 330R | R-10 | R1
1 | BL1-85AXX-20U | BL1-85AXX-20U | J1
1 | OPEN_SOURCE_HW | OPENHW | U$9

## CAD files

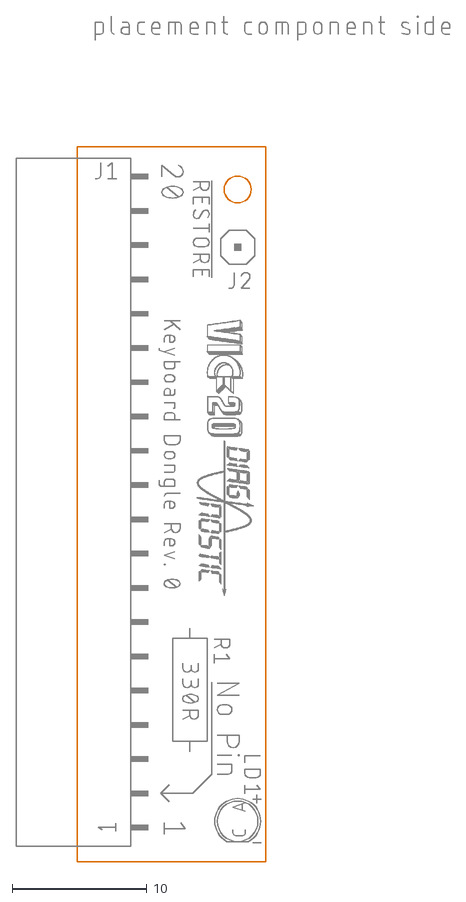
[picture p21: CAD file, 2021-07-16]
Keyboard PCB/Rev. 0/dxf/VIC-20_Diag_Keyboard.dxf
32.2 x 62.7

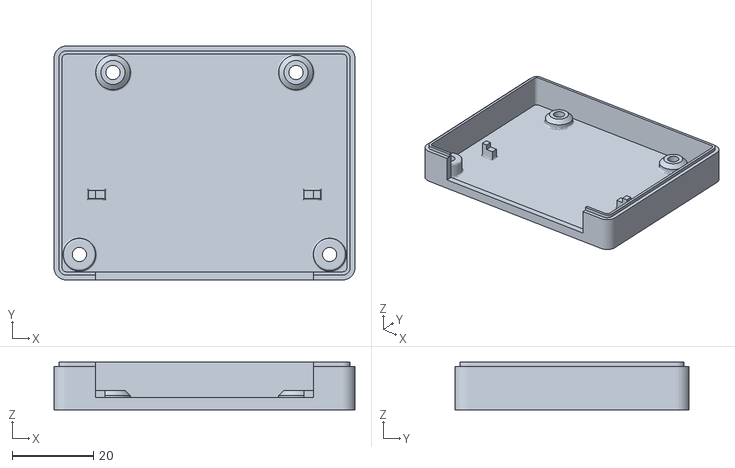
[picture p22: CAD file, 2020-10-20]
User Port PCB/3Dprintable Case/PCB_Rev0/stl/VIC20_diag_up_bottom.stl
74.0 x 57.5 x 11.7

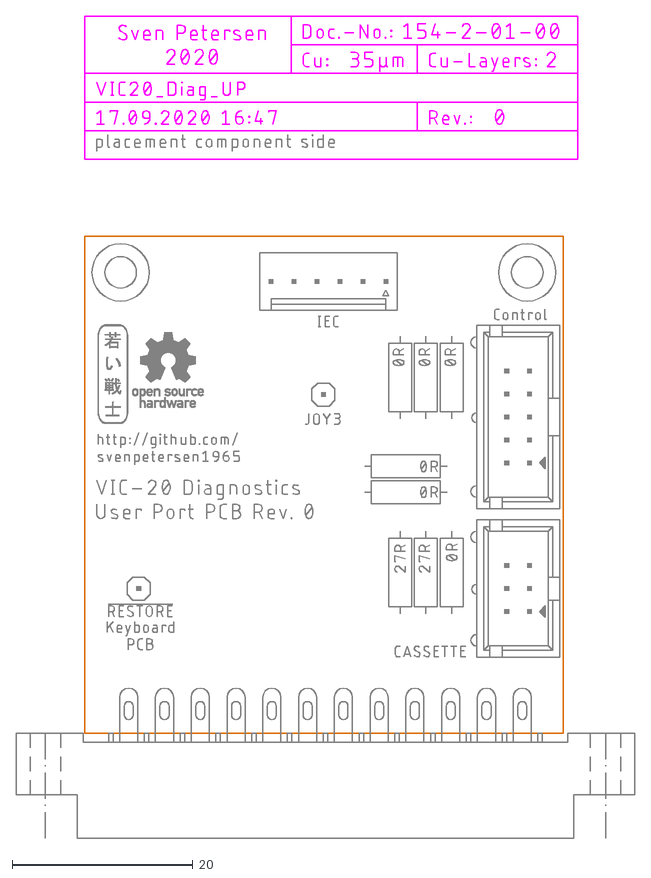
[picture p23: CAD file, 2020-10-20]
User Port PCB/Rev. 0/dxf/VIC20_Diag_UP.dxf
68.5 x 91.0

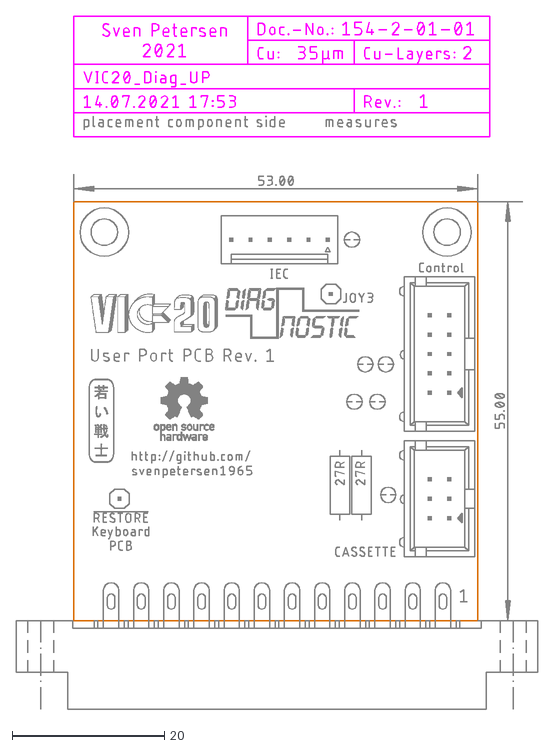
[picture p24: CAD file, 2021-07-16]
User Port PCB/Rev. 1/dxf/VIC20_Diag_UP.dxf
68.5 x 91.0

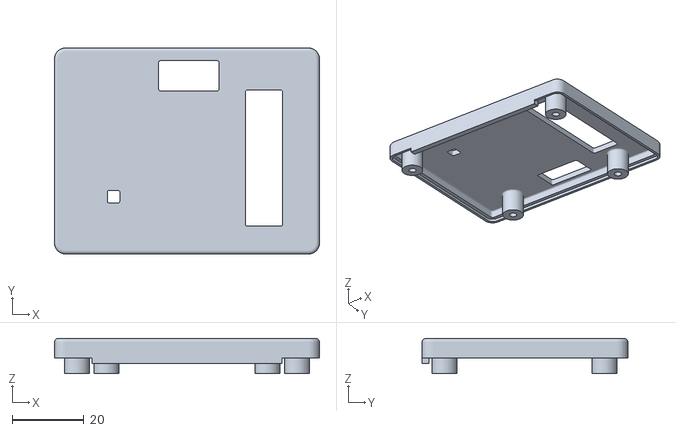
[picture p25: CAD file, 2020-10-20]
User Port PCB/3Dprintable Case/PCB_Rev0/stl/VIC20_diag_up_top.stl
74.0 x 57.5 x 9.80

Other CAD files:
User Port PCB/3Dprintable Case/PCB_Rev0/Fusion 360/VIC20_Diag_UP_PCB_v0 v8.f3d

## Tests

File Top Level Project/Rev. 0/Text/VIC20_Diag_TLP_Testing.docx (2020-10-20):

Commodore VIC-20 Diagnostics Rev. 0

Testing

# Test Setup

The complete Diagnostics Harness (Rev. 0) and Diagnostics Cartridge (Super Expander II Rev. 0 with the Commodore Diagnostic Firmware) was tested on a VIC-20 ASSY 250403 Rev. D.

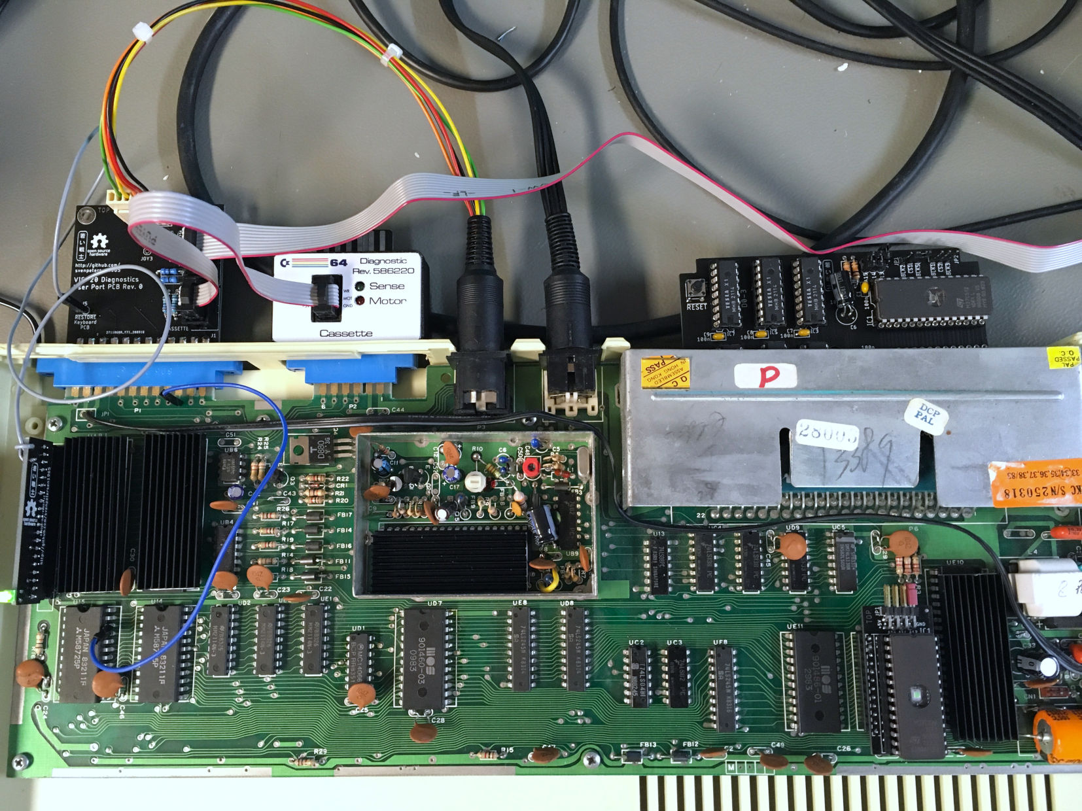
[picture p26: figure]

Figure 1: Test Setup

# Test Execution

The test was first carried out with a Super Expander II with 3kByte of RAM. The Test was running without any problems. Later, the not required upper 2k of RAM were removed from the board, the execution was without any problem, either.

The (Commodore) Test software stops at the first problem and the screen starts flashing. In case no problem is diagnosed, the software is looping infinitely.

There are two versions of the test software. One is for the NTSC VIC-20, the other for the PAL VIC-20. Both were working without problems on a PAL VIC-20. The position of the active was different, though.

The Feedbacks were tested by removing the feedback cables, one by one. The missing feedbacks were detected for the IEC-Bus, the Cassette Port and the Control Port. Removing the Keyboard PCB does not report and “open” like in the C64 Diagnostics Rev. 586220. It did not look like the feedbacks were diagnosed, so, one feedback (not all) was opened. The problem was properly detected.

The Keyboard PCB is detected by the feedbacks and if it is found, the feedback for the RESTORE key is tested. This way, the diagnostic software can be run on a VIC-20, that has the keyboard still connected.

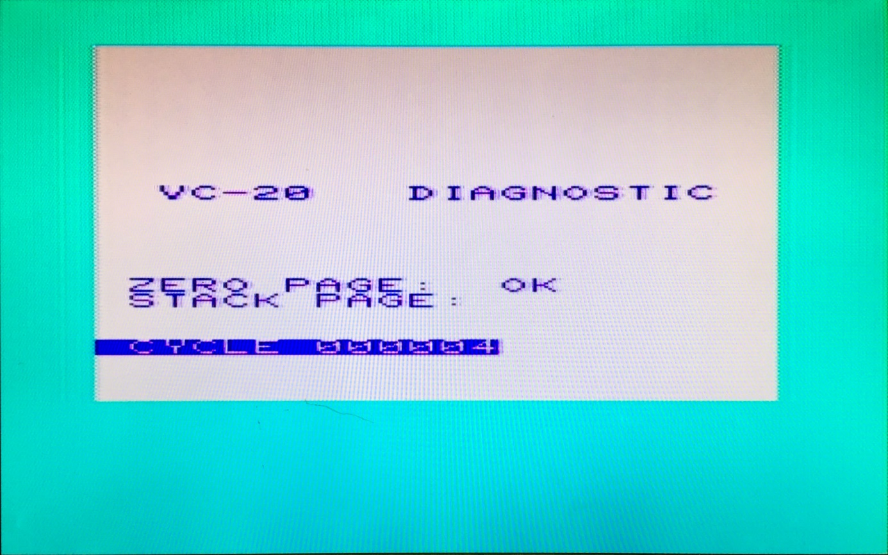
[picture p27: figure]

Figure 2: First page of the PAL diagnostic software

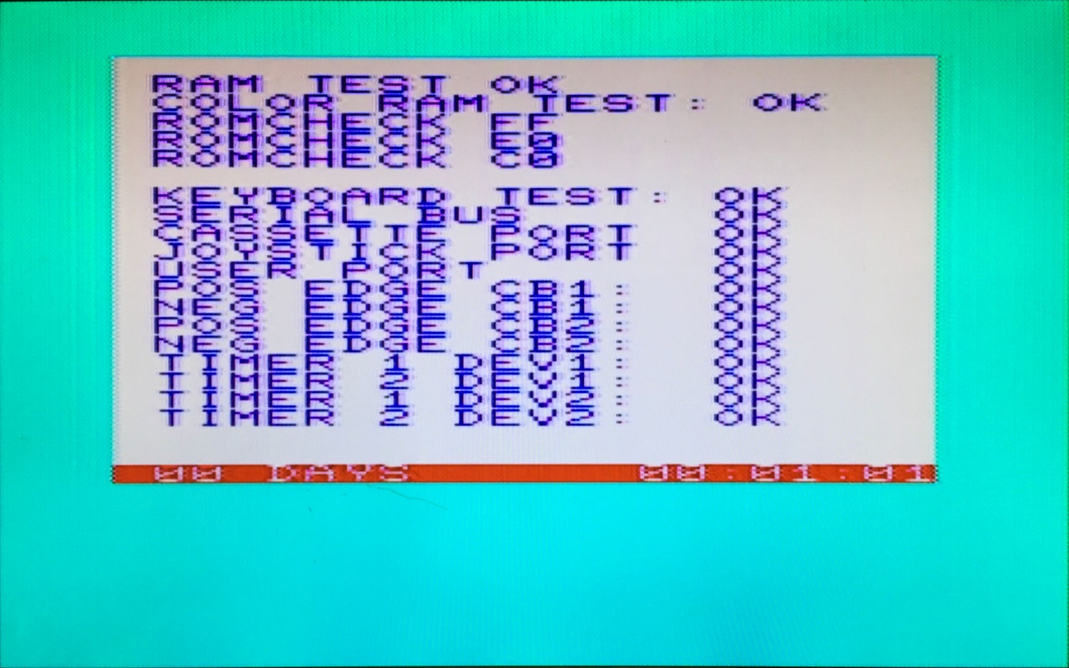
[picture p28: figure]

Figure 3: 2nd page

A JiffyDOS EPROM will not pass the ROM test. It requires to have the original Kernal installed on the VIC-20 to execute the diagnostics properly.

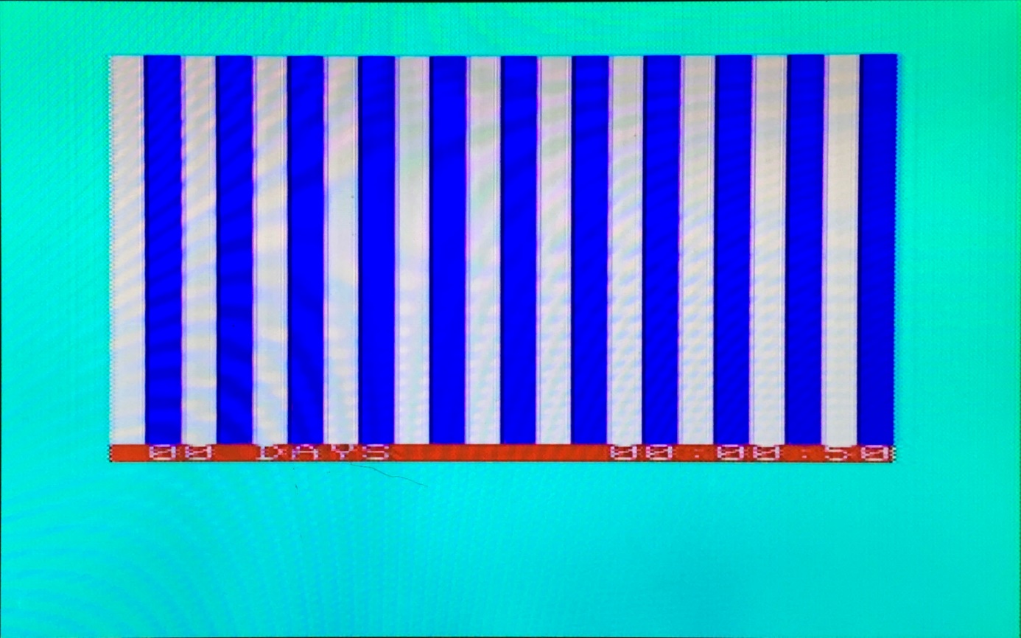
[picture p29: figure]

Figure 4: 3rd screen of the diagnostic test – a display test pattern

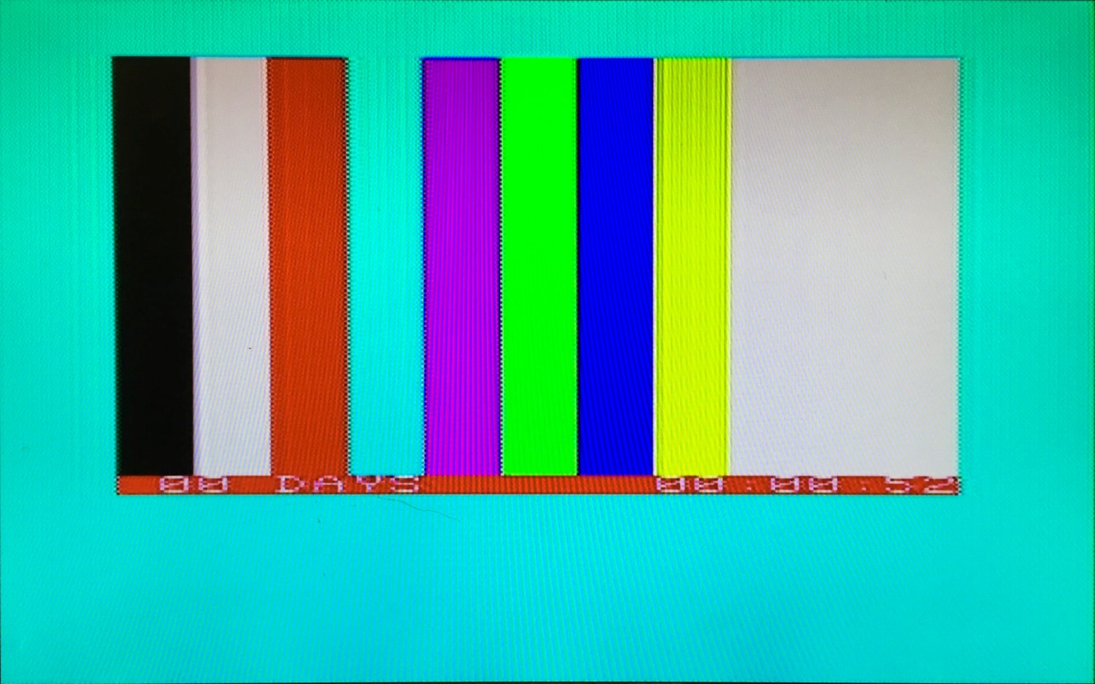
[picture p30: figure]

Figure 5: 4th screen of the diagnostic test - another display test pattern

A sound and display test is part of the diagnostic software.

# Conclusion

The diagnostic harness and cartridge are fully functional.

VIC20_Diag_TLP_Testing.docx 20.10.2020 16:35 Drafted by Sven Petersen Page 2 of 2 Doc.-No.: 161-6-02-00

VIC20_Diag_TLP_Testing.docx 20.10.2020 16:35 Drafted by Sven Petersen Page 1 of 1 Doc.-No.: 000-6-00-00

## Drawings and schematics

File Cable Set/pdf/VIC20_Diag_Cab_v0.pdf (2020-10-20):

# Project Documentation

## Commodore VIC-20: Diagnostic Cable Set

## Project number: 159

## Revision: 0

## Date: 18.10.2020

VIC-20_DiagCab_ModD.docx | | 18.10.2020 16:29
Drafted by Sven Petersen | Page 1 of 1 | Doc.-No.: 159-6-01-00

### Commodore VIC-20: Diagnostics Cable Set – Rev. 0

### Module Description

The Diagnostic cable set is one components of the VIC-20 Diagnostics Harness. It consists of four cables:

- The IEC Port Cable (Doc.-No. 159-3-01-**)
- The Control Port Cable (Doc.-No. 159-3-02-**)
- The Cassette Port Cable (Doc.-No. 159-3-03-**)
- The Keyboard RESTORE cable (Doc.-No. 159-3-04-**)

The Keyboard RESTORE cable is attached to the Keyboard PCB (Project-No. 156), a know serves as a strain relief.

The Control Port cable and the Cassette Port cable are both identical to the cables of the C64 diagnostic harness.

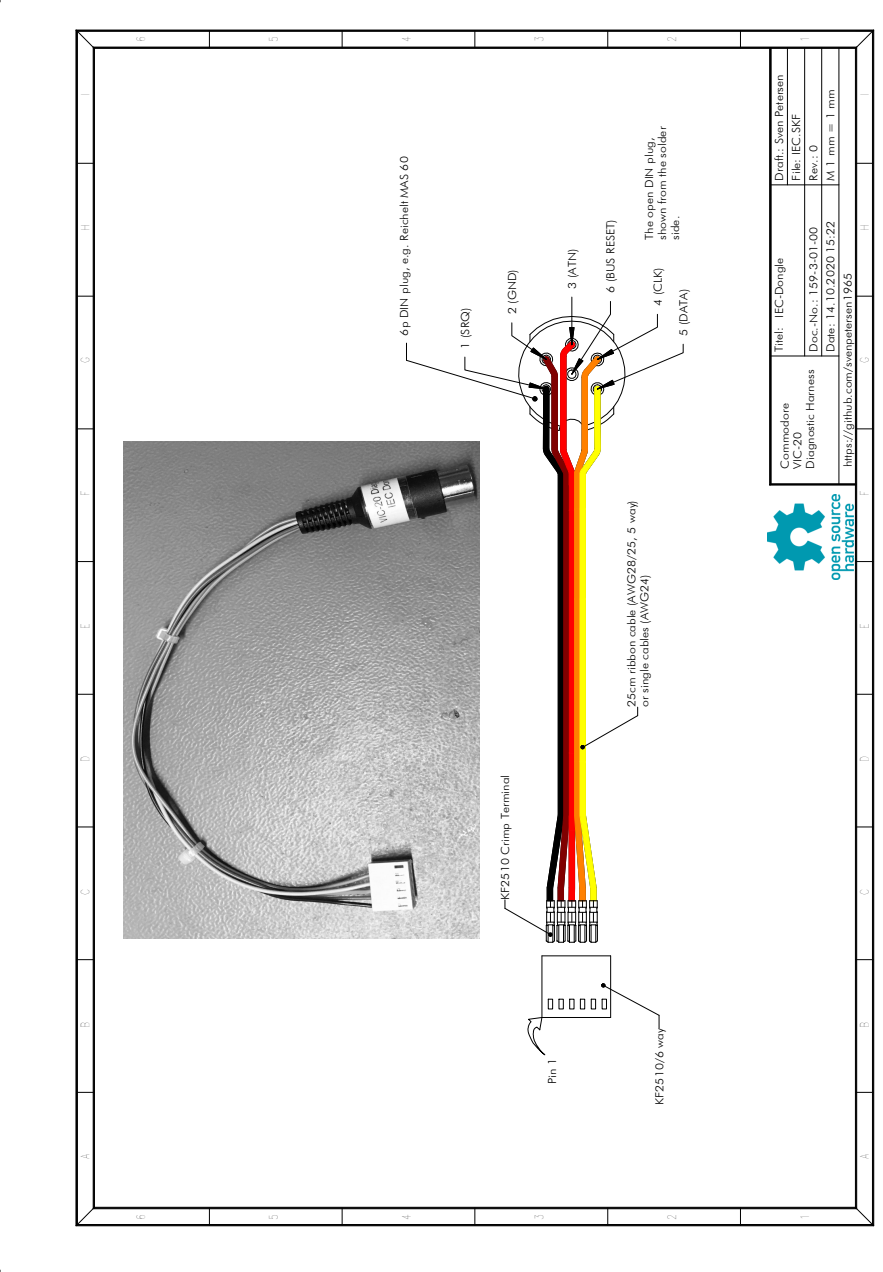
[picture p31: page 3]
IEC.SKF; IEC-Dongle; side.; 1 (SRQ); 2 (GND); 3 (ATN); 6 (BUS RESET); 4 (CLK); 5 (DATA); Pin 1; KF2510/6 way; KF2510 Crimp Terminal; Rev.: 0; 1 File:; Titel:; Doc.-No.: 159-3-01-00; Date: 14.10.2020 15:22; Commodore; VIC-20; Diagnostic Harness

Draft.: Sven Petersen

shown from the solder

The open DIN plug,

6p DIN plug, e.g. Reichelt MAS 60

https://github.com/svenpetersen1965

25cm ribbon cable (AWG28/25, 5 way)

or single cables (AWG24)

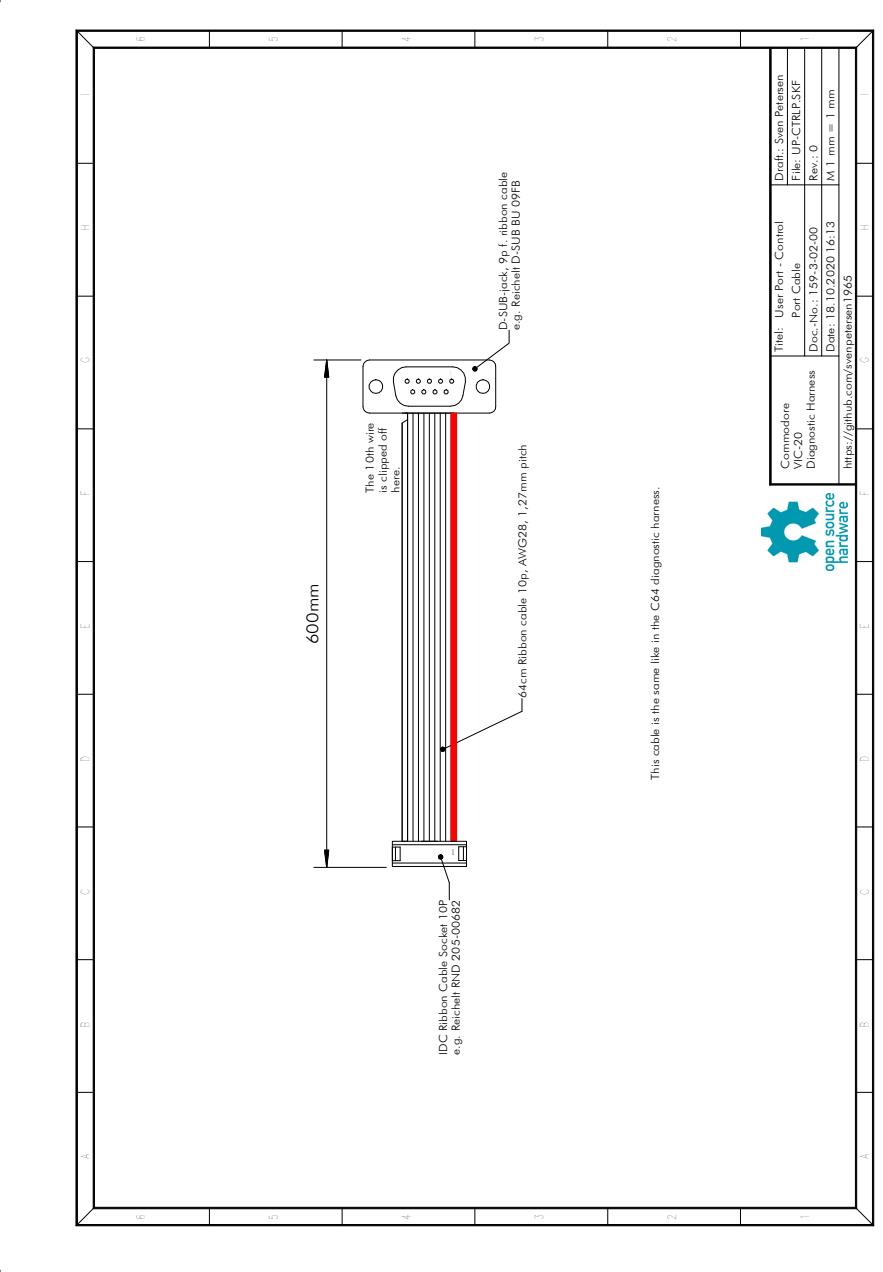
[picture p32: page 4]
Rev.: 0; 1 File:; Titel:; Doc.-No.: 159-3-02-00; Date: 18.10.2020 16:13; e.g. Reichelt RND 205-00682; The 10th wire; here.; Diagnostic Harness

Draft.: Sven Petersen

UP-CTRLP.SKF

D-SUB-jack, 9p f. ribbon cable

e.g. Reichelt D-SUB BU 09FB

User Port - Control

Port Cable 1 1 Commodore VIC-20

https://github.com/svenpetersen1965

is clipped off

64cm Ribbon cable 10p, AWG28, 1,27mm pitch

This cable is the same like in the C64 diagnostic harness.

IDC Ribbon Cable Socket 10P

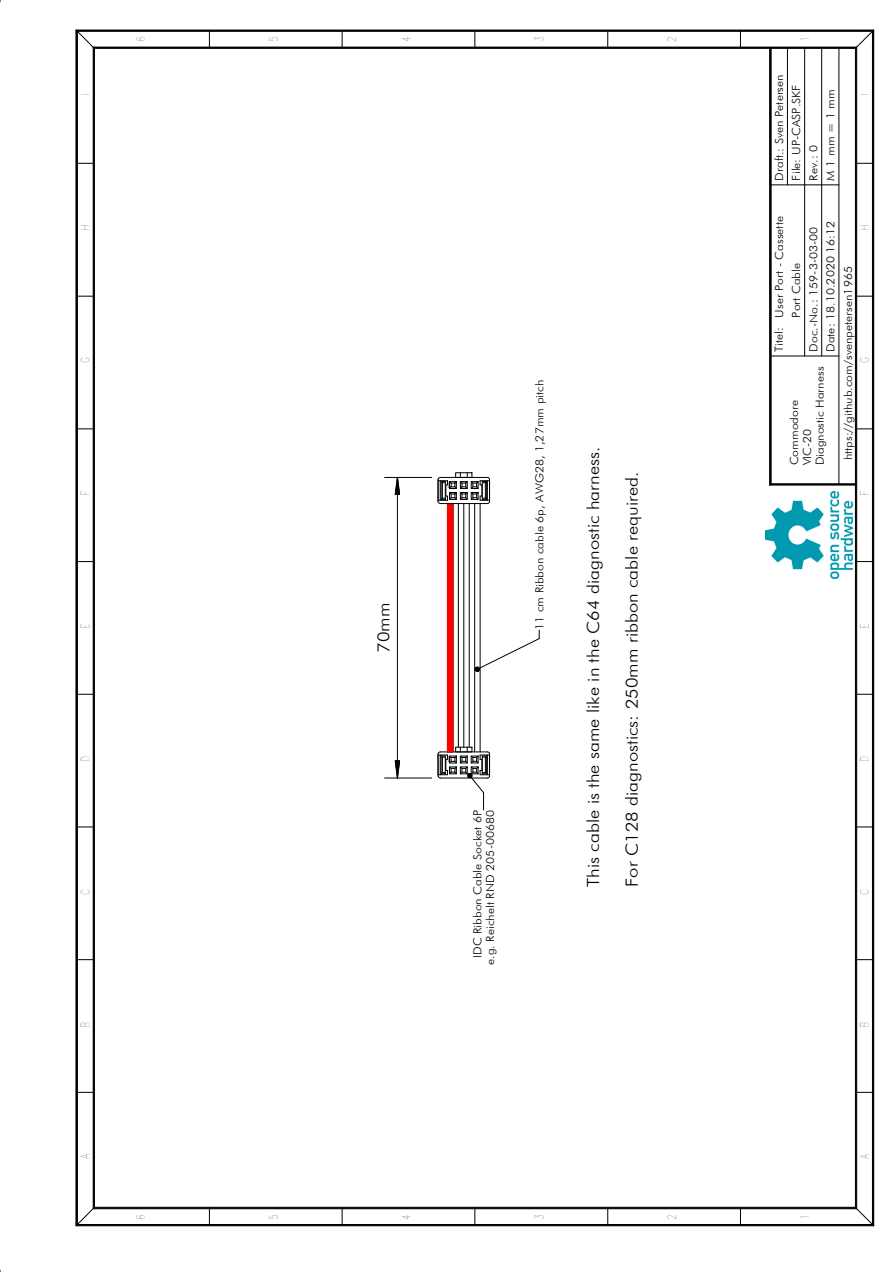
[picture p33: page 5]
Rev.: 0; 1 File:; Titel:; Doc.-No.: 159-3-03-00; Date: 18.10.2020 16:12; Commodore; VIC-20; Diagnostic Harness; e.g. Reichelt RND 205-00680; Port Cable

Draft.: Sven Petersen

UP-CASP.SKF

User Port - Cassette

https://github.com/svenpetersen1965

11 cm Ribbon cable 6p, AWG28, 1,27mm pitch

This cable is the same like in the C64 diagnostic harness.

For C128 diagnostics: 250mm ribbon cable required.

IDC Ribbon Cable Socket 6P

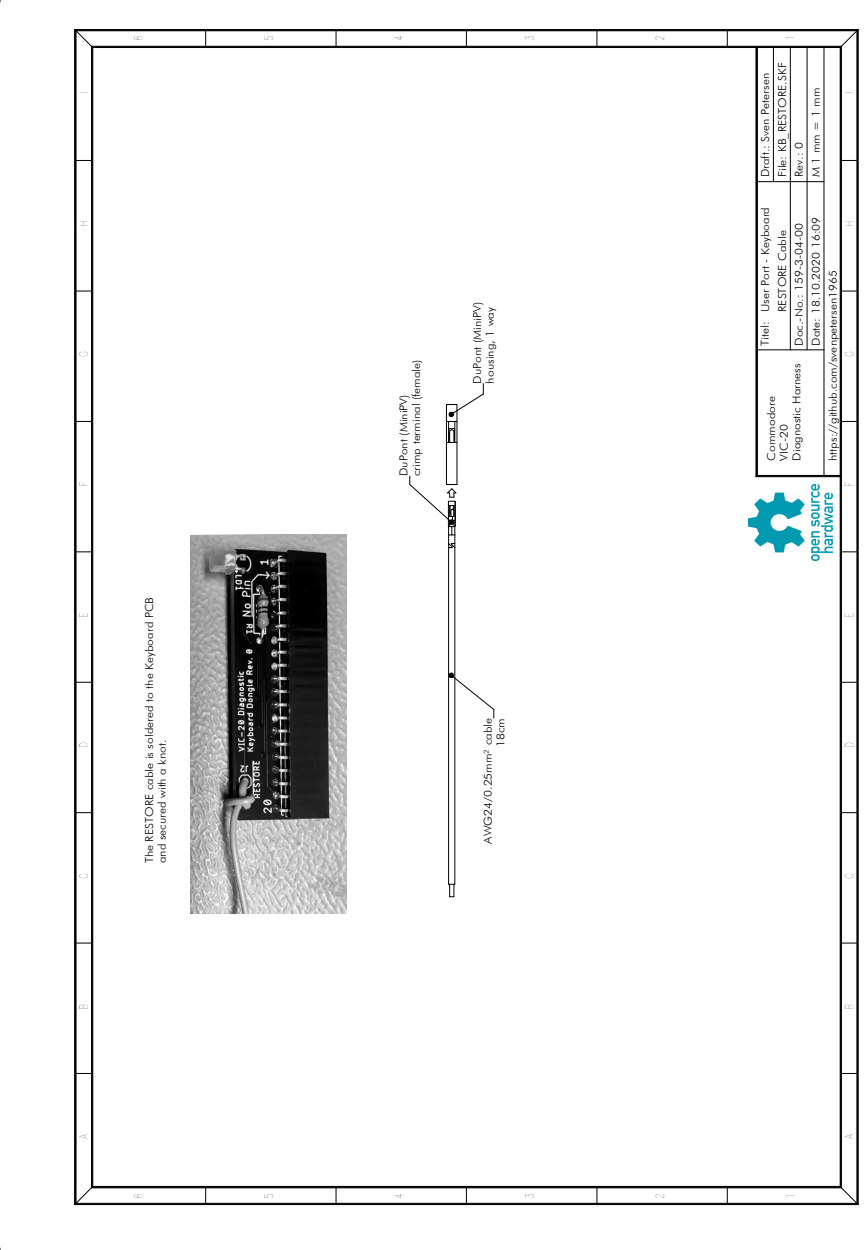
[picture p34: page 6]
Rev.: 0; 1 File:; Titel:; Doc.-No.: 159-3-04-00; Date: 18.10.2020 16:09; KB_RESTORE.SKF; RESTORE Cable; Commodore; VIC-20; Diagnostic Harness; DuPont (MiniPV)

Draft.: Sven Petersen

User Port - Keyboard

https://github.com/svenpetersen1965

housing, 1 way AWG24/0.25mm² cable

crimp terminal (female)

The RESTORE cable is soldered to the Keyboard PCB

and secured with a knot.

Pos. Qty Value Comment

1 1 KF2510/6 way Crimp housing KF2510 (6 way) (Reichelt RND 205-00666) or AliExpress or Molex 22-01-3067

(Reichelt MOLEX 22013067)

2 5 KF2510 Terminals Crimp Terminals for KF2510 (Reichelt RND 205-00696) or AliExpress or Molex 0850-0032

(Reichelt MOLEX 8500032). Attention: KF2510 crimp terminals do not mic with Molex

3 5 25cm Wire AWG24 or 5 way ribbon cable AWG28. Different colors are recommeded

4 2 cable ties small cable ties

5 1 DIN Plug 6 way e.g. Hirschmann MAS60 (Reichelt MAS 60)

6 1 IDC ribbon cable socket 10

way

e.g. Reichelt IDC Ribbon Cable Socket 10P
7 1 64cm ribbon cable 10w, AWG28, 1.27mm pitch (standard)

8 1 Dsub 9, for ribbon cable e.g. Reichelt D-SUB BU 09FB

9 2 IDC ribbon cable socket 6

way

e.g. Reichelt RND 205-00680

10 1 11cm ribbon cable 6w, AWG28, 1.27mm pitch (standard) (or 25cm for combining with C128 diagnostics)

11 1 18cm Wire AWG24

12 1 DuPont crimp terminal (DuPont aka MiniPV). Ebay, AliExpress, other online stores
13 1 DuPont housing 1 way (DuPont aka MiniPV). Ebay, AliExpress, other online stores

## VIC-20 Diagnostic Cable Set Rev. 0

## Bill of Material Rev. 0.0

VIC20_Diag_Cab_BOM_V0_0.xlsx

Drafted by Sven Petersen Page 1 of 1

19.10.2020 20:19
Doc.No.: 159-5-01-00.0

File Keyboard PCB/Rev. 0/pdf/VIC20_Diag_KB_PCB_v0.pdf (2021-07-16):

# Project Documentation

## Commodore VIC-20 Diagnostic Keyboard PCB

## Project number: 156

## Revision: 0

## Date: 15.09.2020


VIC20_Diag_KB_PCB_ModD.docx | | 14.07.2021 17:06
Drafted by Sven Petersen | Page 1 of 2 | Doc.-No.: 156-6-01-00

### Commodore VIC-20 Diagnostic Keyboard PCB Rev. 0

### Module Description

The Keyboard PBC provides the feedbacks for the keyboard connector, which are required for the Commodore VIC-20 Diagnostic software. The LED works as an alternative Power LED.

Figure 1: Dimensions of the Keyboard PCB

## Connectors

### Keyboard Connector (J1)

Pin Signal
1 GND
2 No Pin
3 RESTORE

4 +5V
5 COL7
6 COL6
7 COL5
8 COL4
9 COL3
10 COL2
11 COL1
12 COL0
13 ROW7
14 ROW6
15 ROW5
16 ROW4

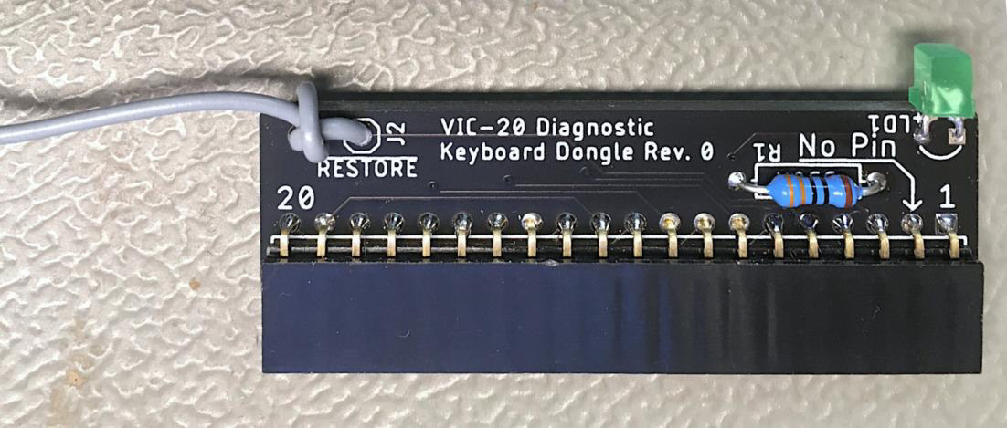
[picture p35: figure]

VIC20_Diag_KB_PCB_ModD.docx | | 14.07.2021 17:06
Drafted by Sven Petersen | Page 2 of 2 | Doc.-No.: 156-6-01-00
Pin | Signal
17 ROW3
18 ROW2
19 ROW1
20 ROW0

### RESTORE Cable (J2)

This is a solder pad for the RESTORE Cable (Doc.-No. 159-3-04-**) from the cable set. The cable is soldered to the pad and a knot serves as a strain relief.

Figure 2: Keyboard PCB with the RESTORE cable soldered to J2 and tied to the PCB

This cable is connected to a single pin of the User Port PCB.

## Interconnects

Signal | Signal
RESTORE | → | User Port Pin 9 (ATN)
COL7 | « | ROW7
COL6 | « | ROW6
COL5 | « | ROW5
COL4 | « | ROW4
COL3 | « | ROW3
COL2 | « | ROW2
COL1 | « | ROW1
COL0 | « | ROW0

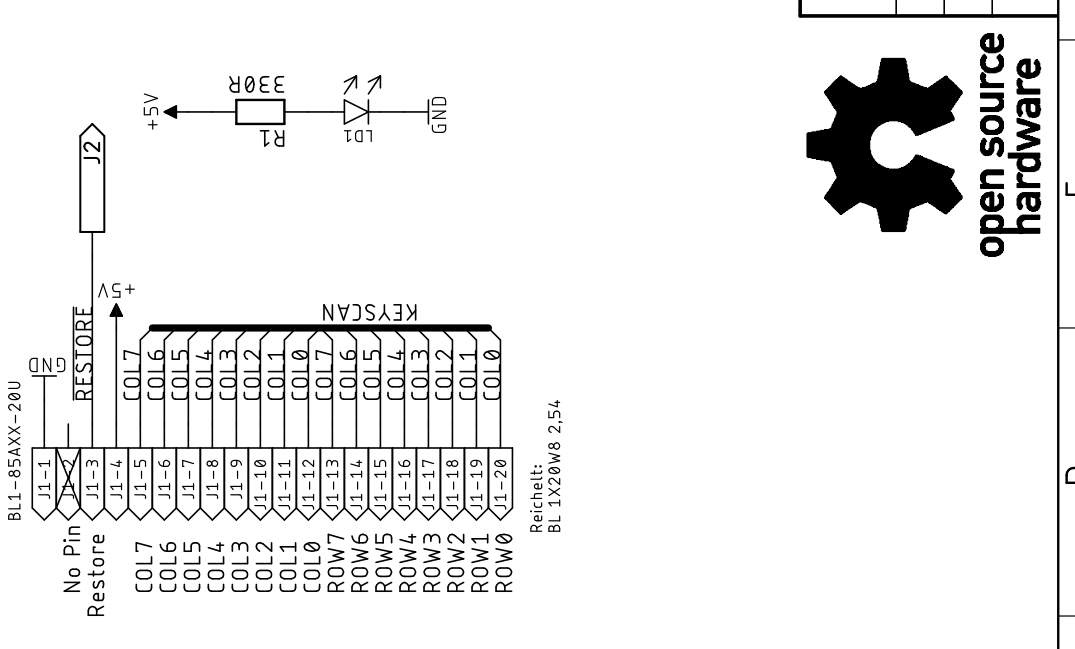
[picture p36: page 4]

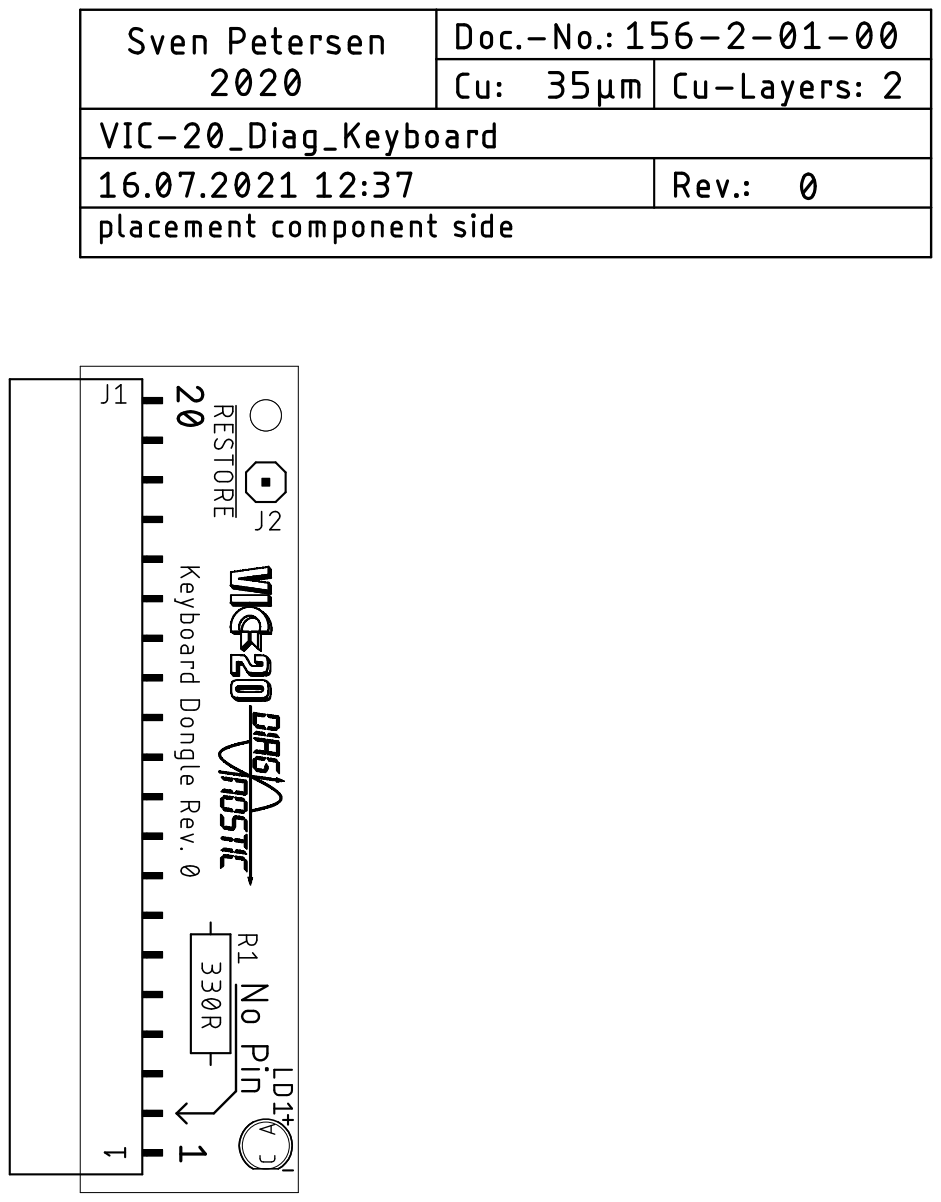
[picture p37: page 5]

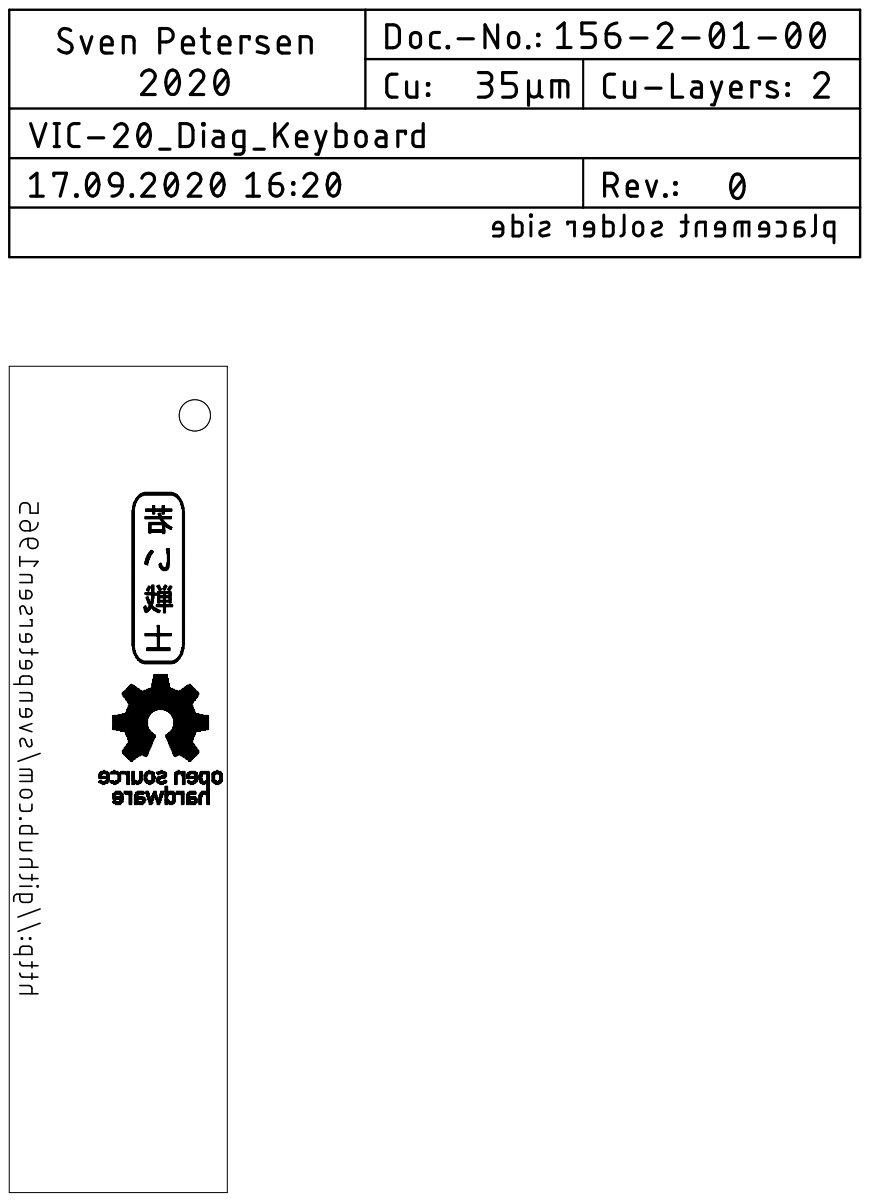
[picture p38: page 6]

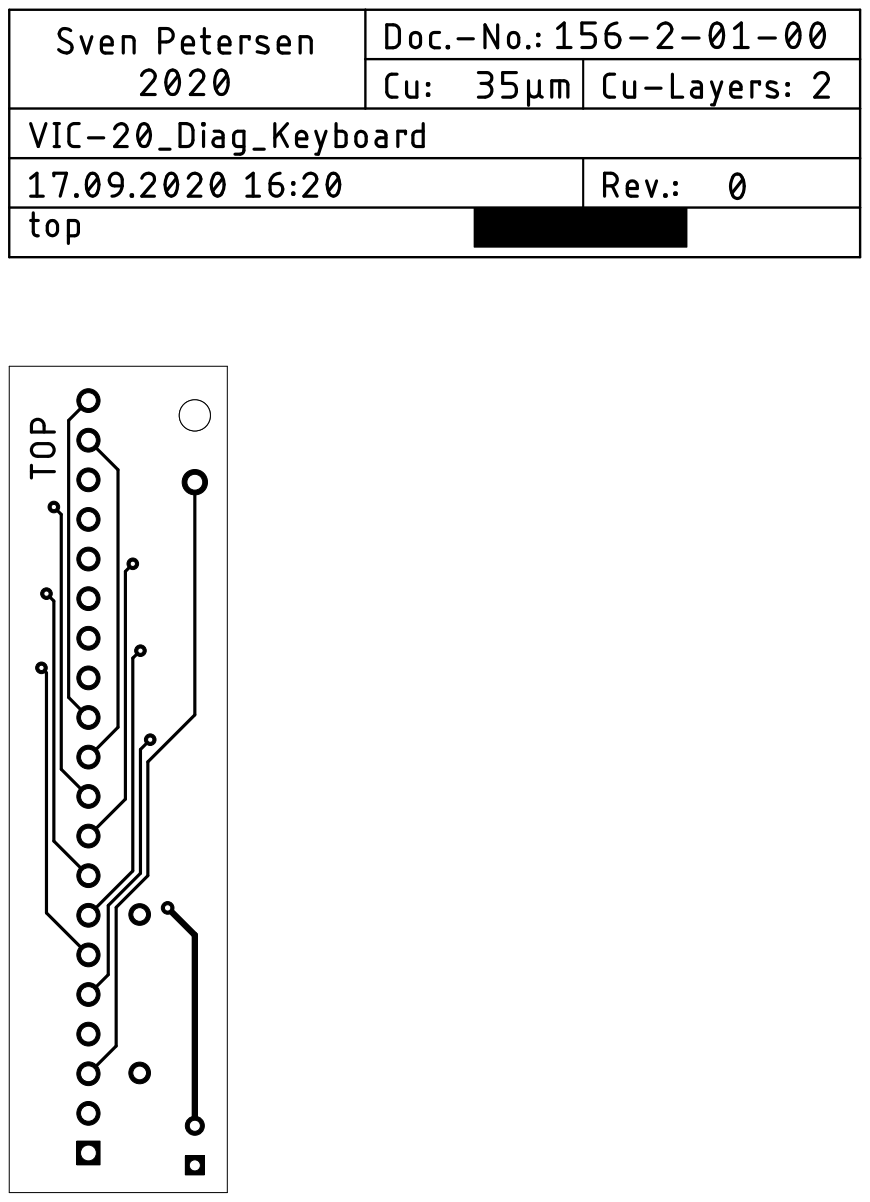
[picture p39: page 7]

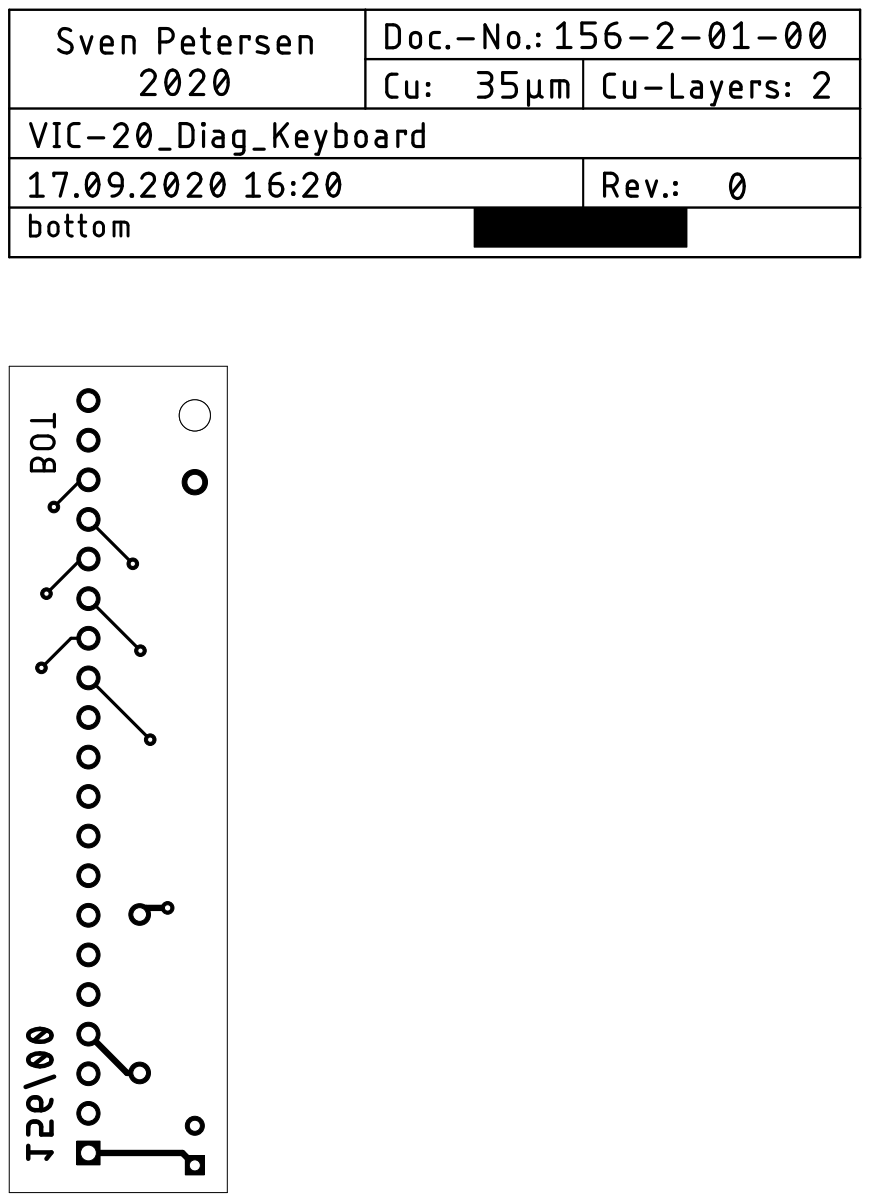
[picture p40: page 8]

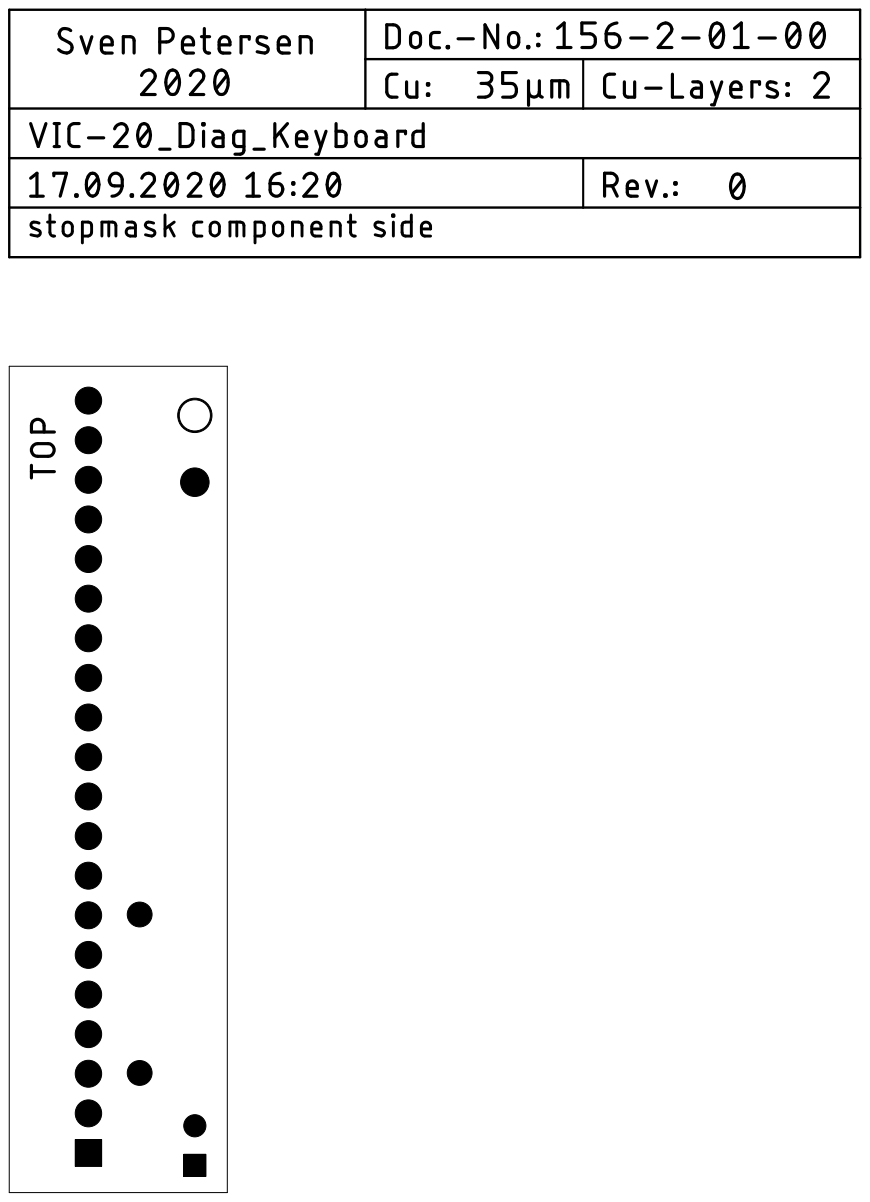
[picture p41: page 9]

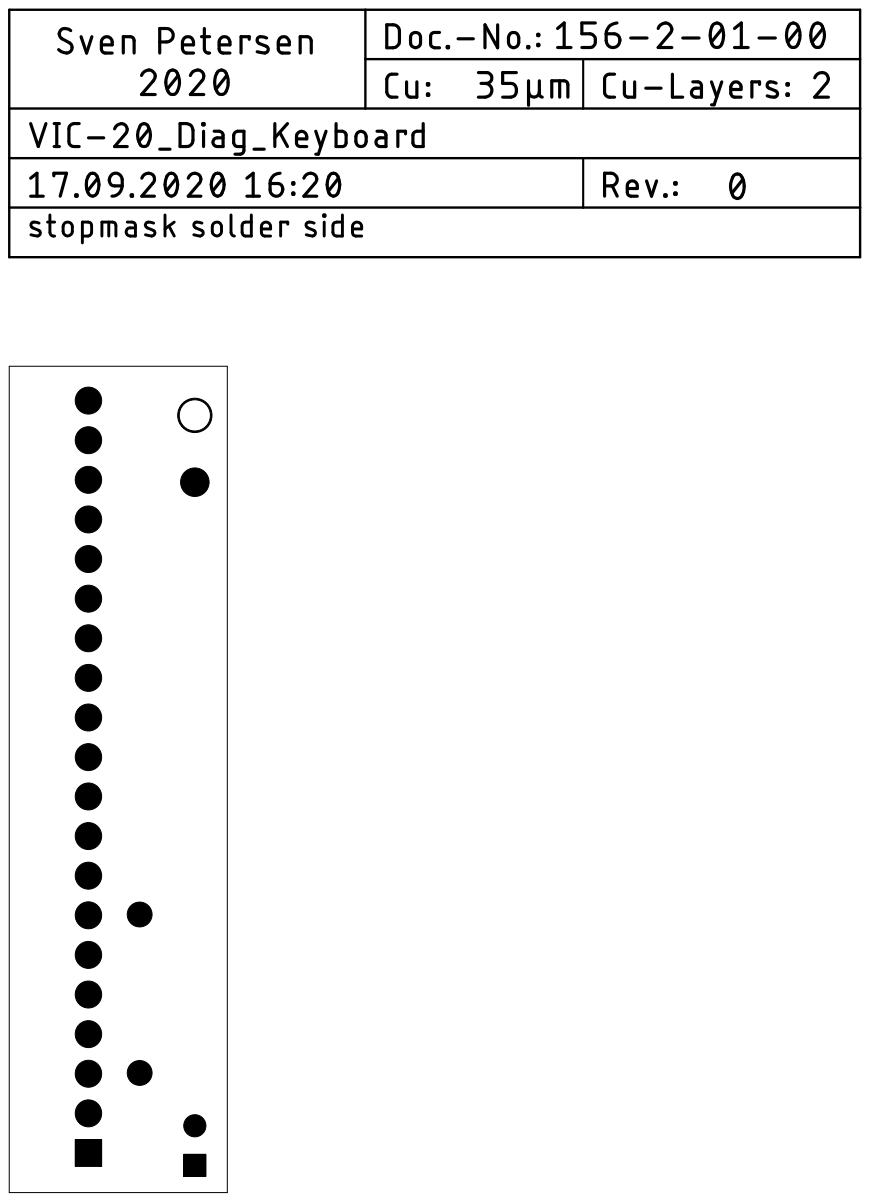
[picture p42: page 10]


Pos. Qty Value Footprint Ref.-No. Comment

1 1 156-2-01-00 2 Layer PCB Rev. 0 2 layer, Cu 35µ, HASL, 53.0mm x 14.0mm, 1.6mm FR4

2 1 3mm/green 3MM LD1 LED

3 1 Restore cable 1X01 J2 Cable (Doc.-No. 159-3-04-**) from cable set soldered to

J2, see module description

4 1 330R R-10 R1 1/4 Watt, 5%

5 1 BL1-85AXX-20U BL1-85AXX-20U J1 20 socket connector, 90°, 2.54mm pitch. E.g. MPE Garry,

Reichelt BL 1x20W8 2,54

## VIC-20 Diagnostic Keyboard PCB Rev. 0

## Bill of Material Rev. 0.0

VIC20_Diag_KBPCB_BOM_v0_0.xlsx

Drafted by Sven Petersen Page 1 of 1

19.10.2020 14:53
Doc.No.: 156-5-01-00.0

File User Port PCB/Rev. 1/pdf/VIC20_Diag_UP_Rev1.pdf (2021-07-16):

# Project Documentation

## Commodore VIC-20 Diagnostic User Port PCB

## Project number: 155

## Revision: 1

## Date: 14.07.2021


VIC20_Diag_UP_ModD.docx | | 16.07.2021 13:00
Drafted by Sven Petersen | Page 1 of 4 | Doc.-No.: 155-6-01-01

### Commodore VIC-20 Diagnostic User Port PCB Rev. 1

### Module Description

Table of content

The VIC-20 Diagnostics User Port PCB provides most of the required feedbacks for the Commodore Diagnostic Software. Those are the feedbacks for the User Port, the IEC (serial) bus and the Cassette Port. Only the keyboard feedbacks are realized on the Diagnostic Keyboard PCB.

Figure 1: Dimensions of the User Port PCB

VIC20_Diag_UP_ModD.docx | | 16.07.2021 13:00
Drafted by Sven Petersen | Page 2 of 4 | Doc.-No.: 155-6-01-01

## Connectors

### User Port

J1- Edge Connector (2x12, 3.96mm pitch)

Pin Signal | Pin Signal
1 | GND | A | GND
2 | +5V | B | CB1
3 | /RESET | C | PB0
4 | JOY0 | D | PB1
5 | JOY1 | E | PB2
6 | JOY2 | F | PB3
7 | LIGHTPEN | H | PB4
8 | CASSSW | J | PB5
9 | ATN | K | PB6
10 | 9VAC(1) | L | PB7
11 | 9VAC(2) | M | CB2
12 | GND | N | GND

### IEC-Bus

J2 – KF2510, 6pin (compatible to Molex KK 254 series, 6p. - P/N 22272061)

Pin | Signal | DIN 6
1 | SQR IN | 1
2 | GND | 2
3 | ATN | 3
4 | CLK | 4
5 | DATA | 5
6 | n.c | -

### Cassette Port

J3 – 2x3 pin header for a ribbon cable connected to the cassette port PCB (project number 114, from the C64 Diagnostic Harness).

Pin Signal | Pin Signal
1 | GND | 2 | n.c.
3 | MOTOR | 4 | READ
5 | WRITE | 6 | SENSE

### Control Port

J4 – 2x5 pin header for a ribbon cable which connects via a D-SUB 9 (female) to the control port.

Pin D-SUB Signal | Pin D-SUB Signal
1 | 1 | JOY0 (up) | 2 | 6 | LIGHTPEN
3 | 2 | JOY1 (down) | 4 | 7 | +5VCTR1
5 | 3 | JOY2 (left) | 6 | 8 | n.c. (GND)
7 | 4 | JOY3 (right) | 8 | 9 | POTX
9 | 5 | POTY | 10 | - | n.c.

VIC20_Diag_UP_ModD.docx | | 16.07.2021 13:00
Drafted by Sven Petersen | Page 3 of 4 | Doc.-No.: 155-6-01-01

## Feedbacks

### User Port (J1)

Pin | Signal | Signal | Pin
B | CB1 | « | IEC-Data | J2/Pin 5
C | PB0 | « | PB1 | D
E | PB2 | « | PB3 | F
H | PB4 | « | PB5 | J
K | PB6 | « | PB7 | L
M | CB2 | « | IEC-Clk | J2/Pin 4
9 | ATN | « | KB RESTORE | See J5

### IEC-Bus (J2)

Pin | Signal | Signal | Pin
1 | SQR_IN | « | ATN | 3
4 | IEC-Clk | « | CB2 (User Port) | J1/Pin M
5 | IEC-Data | « | CB1 (User Port) | J1/Pin B

### Cassette Port (J3)

Pin | Signal | Signal Pin
1 | GND | | n/c | 2
3 | MOTOR | Volt.div. | SENSE | 6
4 | READ | « | WRITE | 5

### Control Port (J4)

DSub | J4 Pin | Signal | Signal | J4 Pin | DSub
1 | 1 | JOY0 | « | JOY1 | 3 | 2
6 | 2 | LIGHTPEN/FIRE | « | JOY2 | 5 | 3
9 | 8 | POTX | « | +5V (Control Port) | 4 | 7
5 | 9 | POTY | « | +5V (Control Port) | 4 | 7

The JOY3 signal is not tested by the original harness. It is connected to the solder pad J6 for experimental purposes.

### Note

The former 0Ω resistor have been replaced with closed (by default) solder bridges. This is to reduce the part count. They don’t serve any purpose, so leave them as is.

## 3D-printed Case

A 3D-printed case for the User Port PCB is available from this repository. The recommended screws are C2.9 x 9.5mm.


VIC20_Diag_UP_ModD.docx | | 16.07.2021 13:00
Drafted by Sven Petersen | Page 4 of 4 | Doc.-No.: 155-6-01-01

Figure 2: User Port PCB with 3D-printed case

## Revision History

### Rev. 0

- Fully working prototype

### Rev. 1

- 0Ω resistors replaced with closed solder bridges to reduce part count
- Cool new logo
- Not yet tested, but low risk modification. Ready for production.








Pos. Qty Value Footprint Ref.-No. Comment

1 1 155-2-01-01 2 Layer PCB Rev. 1 2 layer, Cu 35µ, HASL, 55.0mm x 53.0mm, 1.6mm FR4

2 1 2x3 box connector 2X03WV J3 e.g. Reichelt WSL 6G

3 1 2x5 box connector 2X05WV J4 e.g. Reichelt WSL 10G

4 1 KF2510-6P 6410-6P J2 Reichelt (RND 205-00675), AliExpress or Molex 6410/22-

27-2061 (Reichelt MOLEX 22272061)

5 1 Pin header, 1 pin 1X01 J5 Pin Header, e.g. Reichelt RND 205-00622

6 0 do not place 1X01 J6 do not place

7 2 27R R-10 R4, R5 Metal film resistor, 1/2 W, 5% or better

8 1 2x12, 3.96mm pitch USERPORT J1 edge connector, VIC-20 user port
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

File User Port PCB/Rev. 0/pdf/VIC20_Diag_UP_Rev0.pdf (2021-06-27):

# Project Documentation

## Commodore VIC-20 Diagnostic User Port PCB

## Project number: 155

## Revision: 0

## Date: 15.09.2020


VIC20_Diag_UP_ModD.docx | | 27.06.2021 11:01
Drafted by Sven Petersen | Page 1 of 3 | Doc.-No.: 155-6-01-00

### Commodore VIC-20 Diagnostic User Port PCB Rev. 0

### Module Description

The VIC-20 Diagnostics User Port PCB provides most of the required feedbacks for the Commodore Diagnostic Software. Those are the feedbacks for the User Port, the IEC (serial) bus and the Cassette Port. Only the keyboard feedbacks are realized on the Diagnostic Keyboard PCB.

Figure 1: Dimensions of the User Port PCB

## Connectors

### User Port

J1- Edge Connector (2x12, 3.96mm pitch)

Pin Signal | Pin Signal
1 | GND | A | GND
2 | +5V | B | CB1
3 | /RESET | C | PB0
4 | JOY0 | D | PB1
5 | JOY1 | E | PB2
6 | JOY2 | F | PB3
7 | LIGHTPEN | H | PB4
8 | CASSSW | J | PB5
9 | ATN | K | PB6
10 | 9VAC(1) | L | PB7
11 | 9VAC(2) | M | CB2
12 | GND | N | GND

VIC20_Diag_UP_ModD.docx | | 27.06.2021 11:01
Drafted by Sven Petersen | Page 2 of 3 | Doc.-No.: 155-6-01-00

### IEC-Bus

J2 – KF2510, 6pin (compatible to Molex KK 254 series, 6p. - P/N 22272061)

Pin | Signal | DIN 6
1 | SQR IN | 1
2 | GND | 2
3 | ATN | 3
4 | CLK | 4
5 | DATA | 5
6 | n.c | -

### Cassette Port

J3 – 2x3 pin header for a ribbon cable connected to the cassette port PCB (project number 114, from the C64 Diagnostic Harness).

Pin Signal | Pin Signal
1 | GND | 2 | n.c.
3 | MOTOR | 4 | READ
5 | WRITE | 6 | SENSE

### Control Port

J4 – 2x5 pin header for a ribbon cable which connects via a D-SUB 9 (female) to the control port.

Pin D-SUB Signal | Pin D-SUB Signal
1 | 1 | JOY0 (up) | 2 | 6 | LIGHTPEN
3 | 2 | JOY1 (down) | 4 | 7 | +5VCTR1
5 | 3 | JOY2 (left) | 6 | 8 | n.c. (GND)
7 | 4 | JOY3 (right) | 8 | 9 | POTX
9 | 5 | POTY | 10 | - | n.c.

## Feedbacks

### User Port (J1)

Pin | Signal | Signal | Pin
B | CB1 | « | IEC-Data | J2/Pin 5
C | PB0 | « | PB1 | D
E | PB2 | « | PB3 | F
H | PB4 | « | PB5 | J
K | PB6 | « | PB7 | L
M | CB2 | « | IEC-Clk | J2/Pin 4
9 | ATN | « | KB RESTORE | See J5

### IEC-Bus (J2)

Pin | Signal | Signal | Pin
1 | SQR_IN | « | ATN | 3
4 | IEC-Clk | « | CB2 (User Port) | J1/Pin M
5 | IEC-Data | « | CB1 (User Port) | J1/Pin B


VIC20_Diag_UP_ModD.docx | | 27.06.2021 11:01
Drafted by Sven Petersen | Page 3 of 3 | Doc.-No.: 155-6-01-00

### Cassette Port (J3)

Pin | Signal | Signal Pin
1 | GND | | n/c | 2
3 | MOTOR | Volt.div. | SENSE | 6
4 | READ | « | WRITE | 5

### Control Port (J4)

DSub | J4 Pin | Signal | Signal | J4 Pin | DSub
1 | 1 | JOY0 | « | JOY1 | 3 | 2
6 | 2 | LIGHTPEN/FIRE | « | JOY2 | 5 | 3
9 | 8 | POTX | « | +5V (Control Port) | 4 | 7
5 | 9 | POTY | « | +5V (Control Port) | 4 | 7

The JOY3 signal is not tested by the original harness. It is connected to the solder pad J6 for experimental purposes.

### Note

There are a couple of 0Ω resistors on the PCB. They are for leaving the option of inserting a resistor with an impedance >0Ω, in case it might be required in the future. They can be replaced with wire bridges.

## 3D-printed Case

A 3D-printed case for the User Port PCB is available from this repository. The recommended screws are C2.9 x 9.5mm.

Figure 2: User Port PCB with 3D-printed case








Pos. Qty Value Footprint Ref.-No. Comment

1 1 155-2-01-00 2 Layer PCB Rev. 0 2 layer, Cu 35µ, HASL, 55.0mm x 53.0mm, 1.6mm FR4

2 1 2x3 box connector 2X03WV J3 e.g. Reichelt WSL 6G

3 1 2x5 box connector 2X05WV J4 e.g. Reichelt WSL 10G

4 1 KF2510-6P 6410-6P J2 Reichelt (RND 205-00675), AliExpress or Molex 6410/22-

27-2061 (Reichelt MOLEX 22272061)

5 1 Pin header, 1 pin 1X01 J5 Pin Header, e.g. Reichelt RND 205-00622

6 0 do not place 1X01 J6 do not place

7 6 0R R-10 R1, R2, R3, R6, R7, R8 0 Ohm resistor, alternative: wire bridge
8 2 27R R-10 R4, R5 Metal film resistor, 1/2 W, 5% or better

9 1 2x12, 3.96mm pitch USERPORT J1 edge connector, VIC-20 user port

# VIC-20 Diagnostic User Port PCB Rev. 0 Bill of Material Rev. 0.0

VIC20_Diag_UP_BOM_V0_0.xlsx

Drafted by Sven Petersen Page 1 of 1

19.10.2020 10:33
Doc.No.: 155-5-01-00.0

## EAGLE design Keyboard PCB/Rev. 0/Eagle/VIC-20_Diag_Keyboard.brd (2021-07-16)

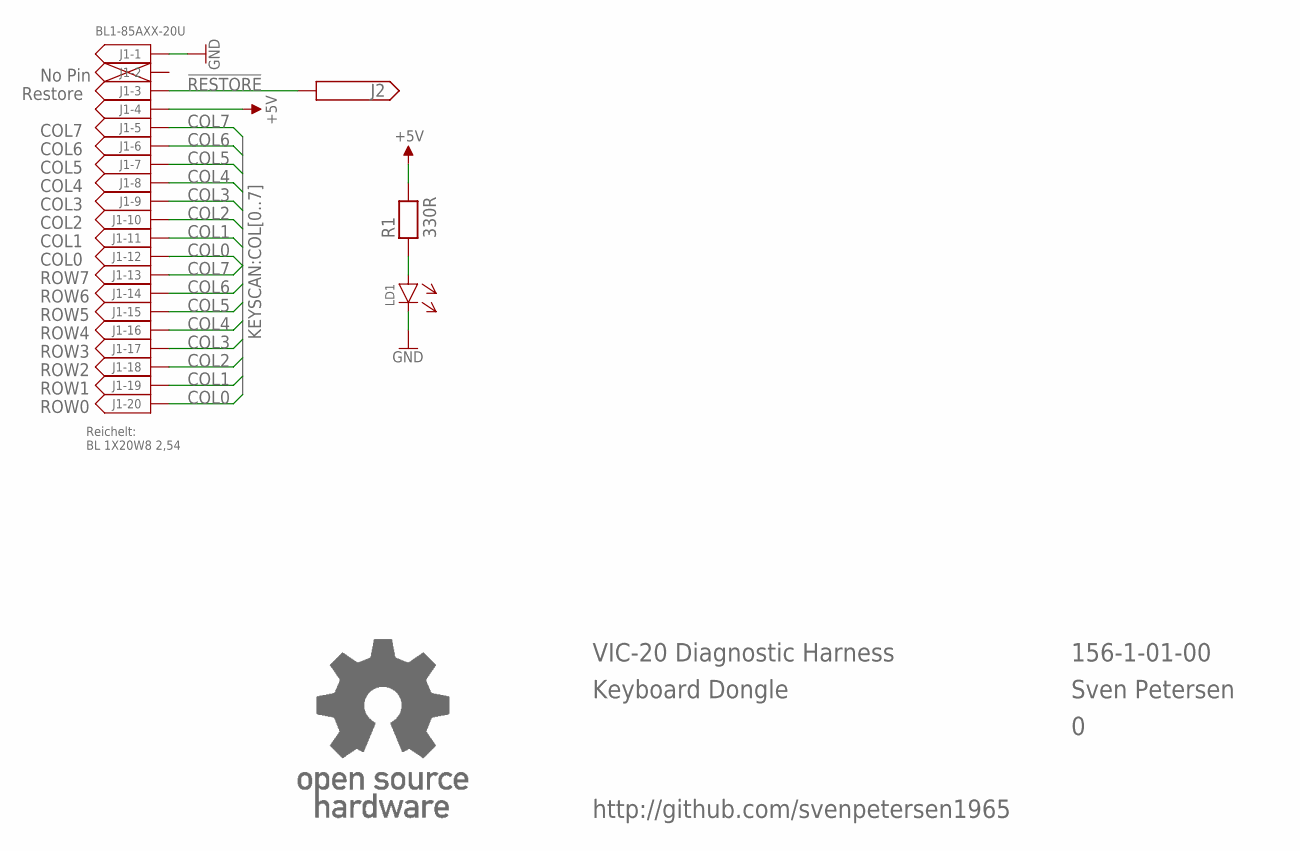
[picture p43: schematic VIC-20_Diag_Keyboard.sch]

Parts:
J1: BL1-85AXX-20U
J2: PINHD-1X1; 1X01
LD1: 3MM
R1: 330R; R-10
U$9: OPEN_SOURCE_HW; OPENHW

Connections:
!RESTORE: J1.3, J2.1
+5V: J1.4, R1.2
COL0: J1.12, J1.20
COL1: J1.11, J1.19
COL2: J1.10, J1.18
COL3: J1.9, J1.17
COL4: J1.8, J1.16
COL5: J1.7, J1.15
COL6: J1.6, J1.14
COL7: J1.5, J1.13
GND: J1.1, LD1.C (K)
unnamed: LD1.A, R1.1

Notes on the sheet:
COL7
COL6
COL5
COL4
COL3
COL2
COL1
COL0
ROW7
ROW6
ROW5
ROW4
ROW3
ROW2
ROW1
ROW0
No Pin
Restore
VIC-20 Diagnostic Harness
Keyboard Dongle
156-1-01-00
Sven Petersen
Reichelt: BL 1X20W8 2,54
http://github.com/svenpetersen1965

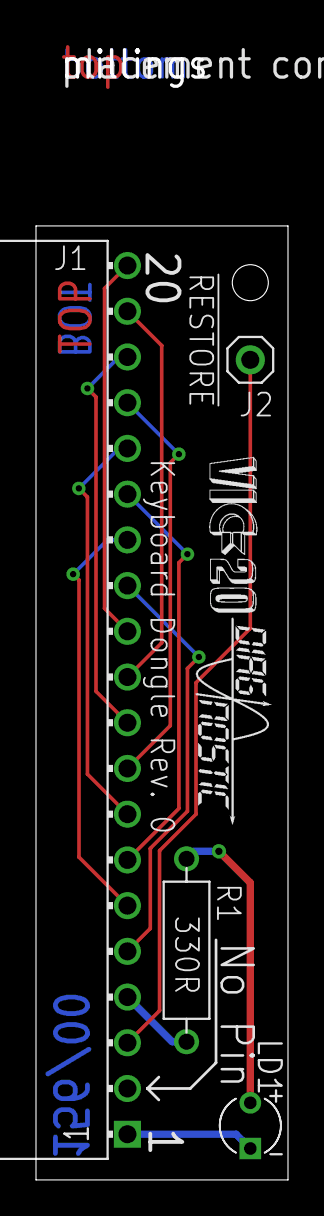
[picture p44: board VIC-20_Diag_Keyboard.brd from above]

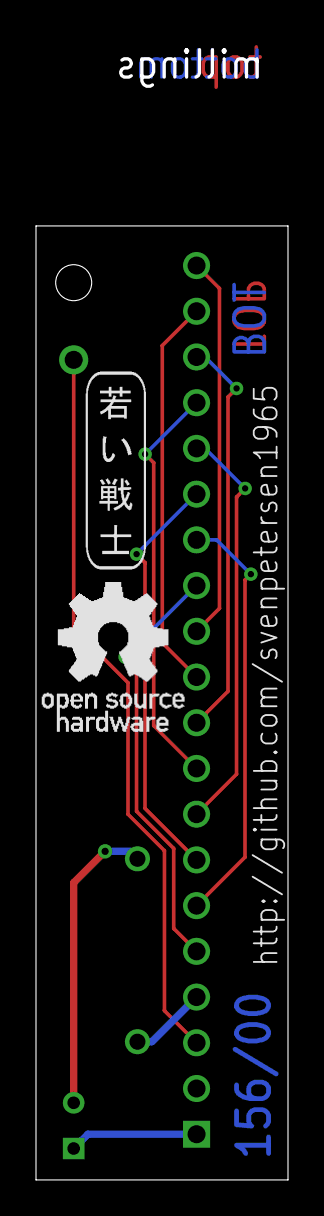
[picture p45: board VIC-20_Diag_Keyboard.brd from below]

Board: 2 copper layers, 14.0 x 53.0 mm, 9 parts (2 on the bottom side), 12 nets.

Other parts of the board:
U$6: 2LAYER
U$7: PCB-TITLE/
U$8: SVEN_TAG
U$10: VIC20_DIAG_SMALL

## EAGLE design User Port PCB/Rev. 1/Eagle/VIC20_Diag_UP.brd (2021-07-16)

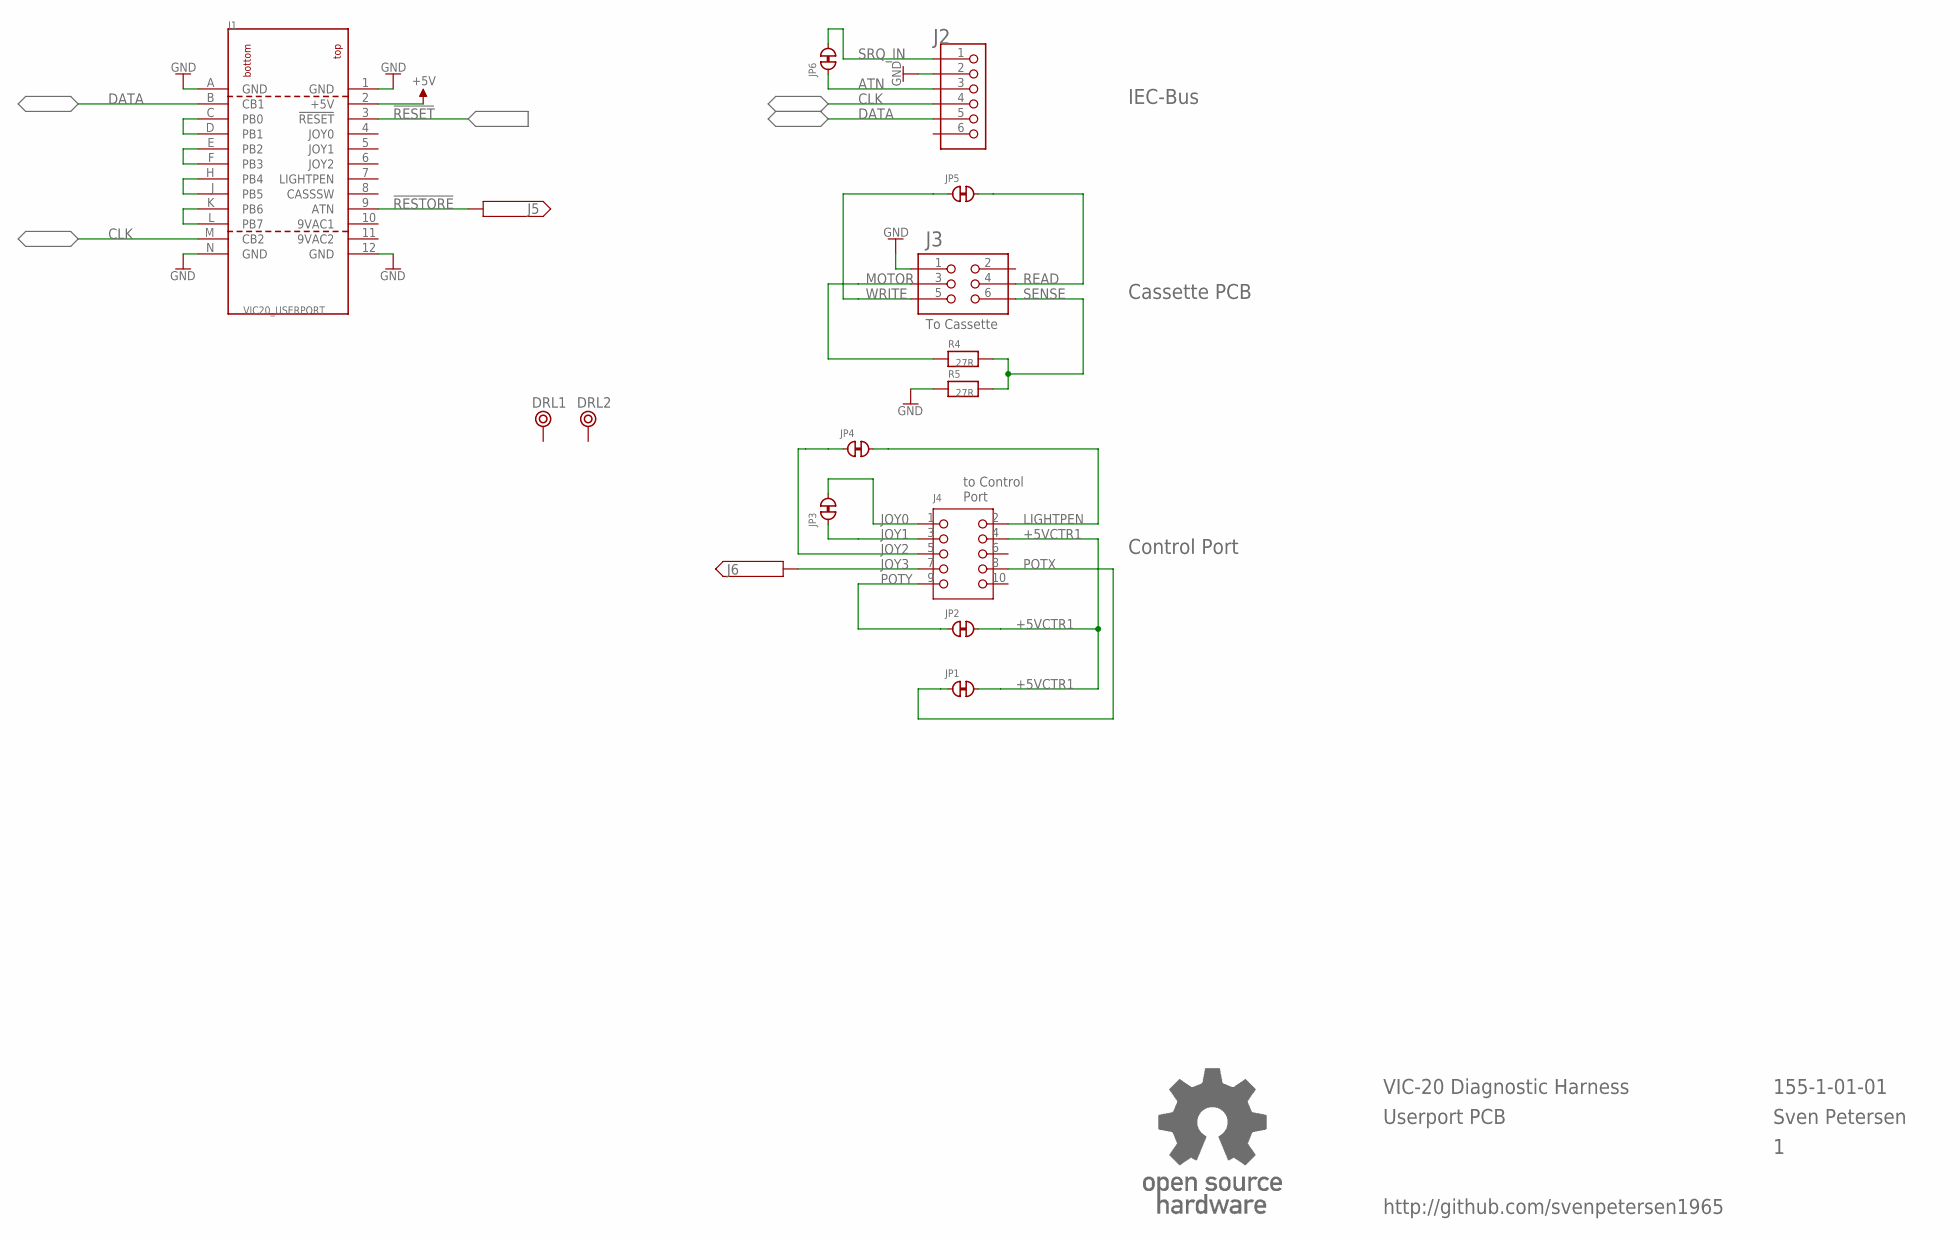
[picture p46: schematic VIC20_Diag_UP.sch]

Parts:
DRL1, DRL2: BOHR3,5
J1: VIC20_USERPORT; USERPORT
J2: 6410-6P
J3: 2X03WV
J4: 2X05WV
J5, J6: PINHD-1X1; 1X01
JP1, JP2, JP3, JP4, JP5, JP6: CLOSED; CP_CL
R4, R5: 27R; R-10
U$2: OPEN_SOURCE_HW; OPENHW

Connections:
9VAC1: J1.10 (9VAC1)
9VAC2: J1.11 (9VAC2)
!RESET: J1.3 (!RESET)
!RESTORE: J1.9 (ATN), J5.1
+5V: J1.2 (+5V)
+5VCTR1: J4.4, JP1.2, JP2.2
ATN: J2.3, JP6.1
CLK: J1.M (CB2), J2.4
DATA: J1.B (CB1), J2.5
GND: J1.1 (GND), J1.12 (GND), J1.A (GND), J1.N (GND), J2.2, J3.1, R5.1
JOY0: J4.1, JP3.2
JOY1: J4.3, JP3.1
JOY2: J4.5, JP4.1
JOY3: J4.7, J6.1
LIGHTPEN: J4.2, JP4.2
MOTOR: J3.3, R4.1
unnamed: J1.C (PB0), J1.D (PB1)
unnamed: J1.E (PB2), J1.F (PB3)
unnamed: J1.H (PB4), J1.J (PB5)
unnamed: J1.K (PB6), J1.L (PB7)
POTX: J4.8, JP1.1
POTY: J4.9, JP2.1
READ: J3.4, JP5.2
SENSE: J3.6, R4.2, R5.2
SRQ_IN: J2.1, JP6.2
WRITE: J3.5, JP5.1

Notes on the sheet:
To Cassette
to Control Port
155-1-01-01
Sven Petersen
VIC-20 Diagnostic Harness
Userport PCB
IEC-Bus
Cassette PCB
Control Port
http://github.com/svenpetersen1965

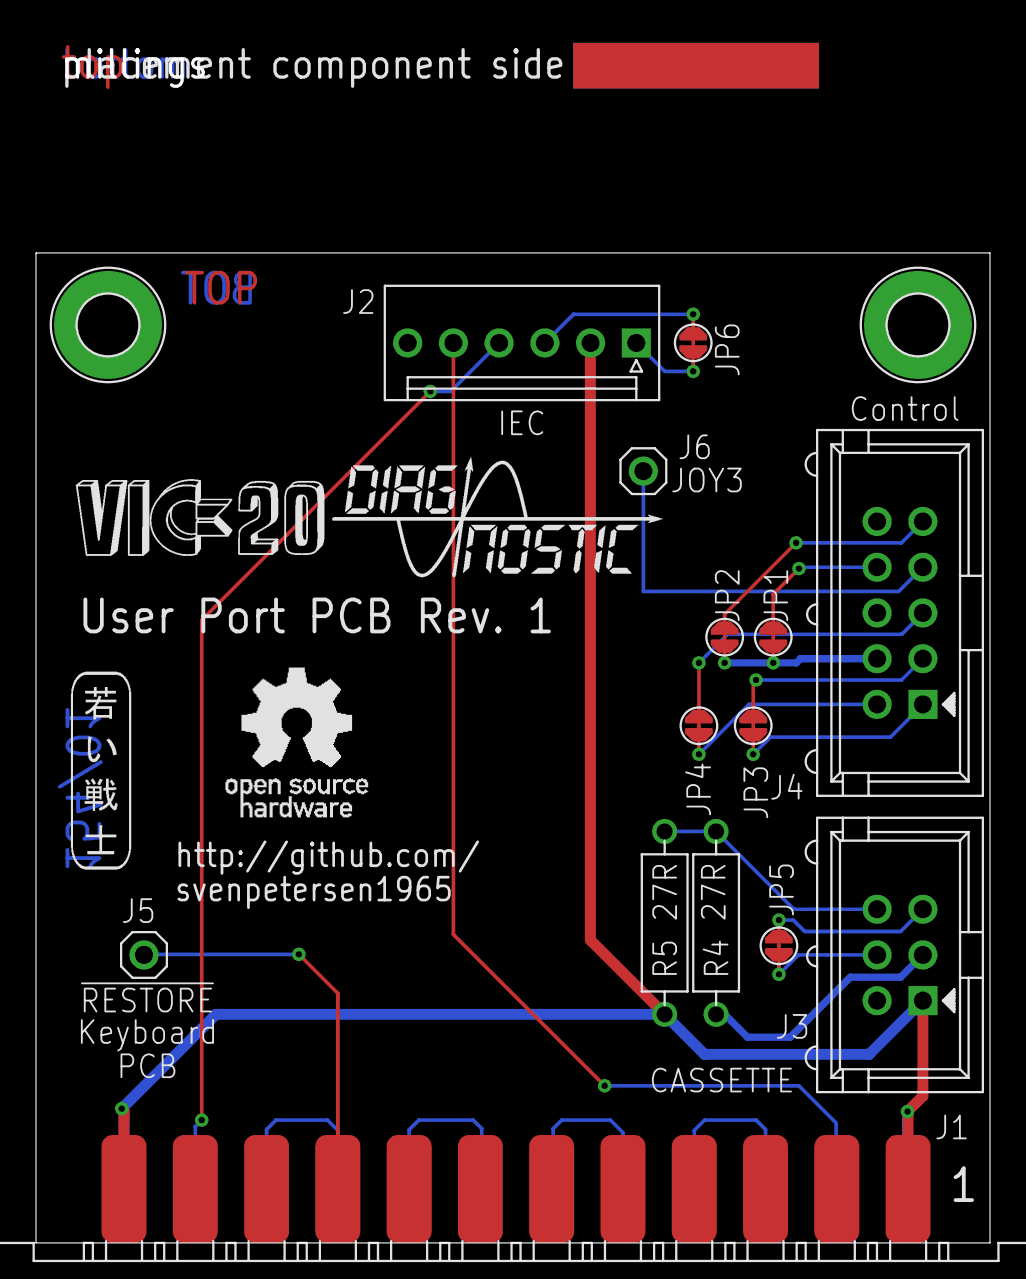
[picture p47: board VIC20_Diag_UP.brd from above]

Board: 2 copper layers, 53.0 x 55.0 mm, 21 parts (0 on the bottom side), 22 nets.

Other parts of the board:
U$10: SVEN_TAG
U$17: PCB-TITLE/
U$18: 2LAYER
U$19: VIC20_DIAG

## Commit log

2021-07-16 Rev. 1 released
    No functional update, reduced part count, new logo
    [VIC20_Diag_UP.brd, VIC20_Diag_UP.dxf, VIC20_Diag_UP.sch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]
2021-07-16 Silk Screen Update
    Just a new logo
    [VIC-20_Diag_Keyboard.brd, VIC-20_Diag_Keyboard.dxf, VIC20_Diag_KBPCB_BOM_v0_0_calc.xlsx]
